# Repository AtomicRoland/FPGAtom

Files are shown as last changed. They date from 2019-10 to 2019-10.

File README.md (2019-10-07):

# FPGAtom

These are the KiCad files of the MK2 boards for the Atom 2k18 a.k.a. FPGAtom. The production files of the MK1 boards are also included but you don't want to use these :-).

For support, create an issue on Github or post your question or remark on the StarDot forums: https://stardot.org.uk/forums/viewtopic.php?f=44&t=15197

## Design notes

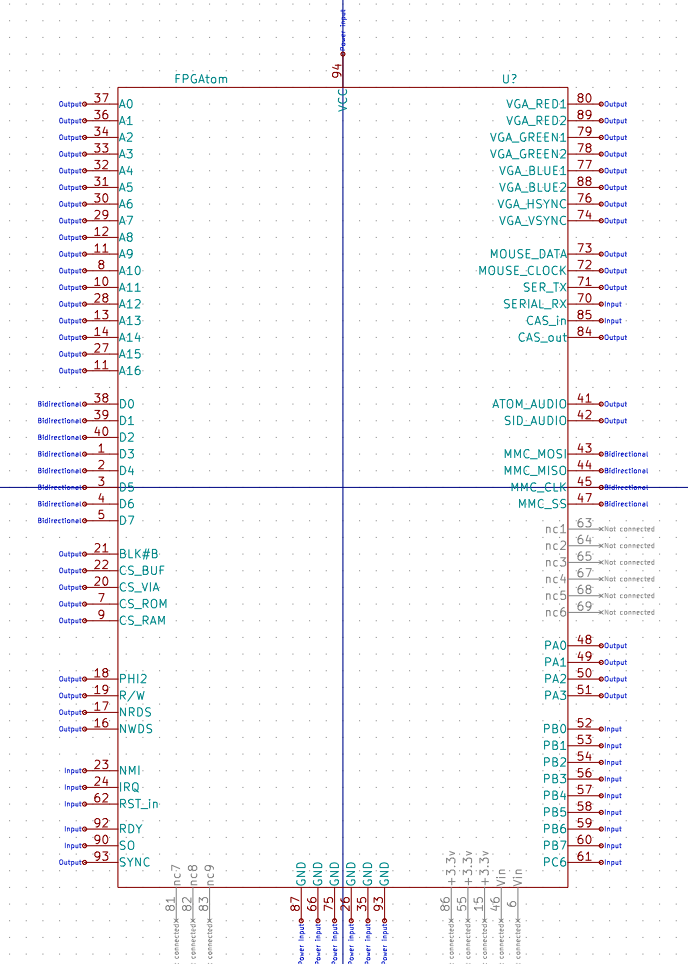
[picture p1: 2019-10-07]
FPGAtom.png

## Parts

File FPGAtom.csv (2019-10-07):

Id | Designator | Package | Quantity | Designation | Supplier and ref
1 | U11 | FPGAmodule | 1 | FPGAtom
2 | R53,R52,R1,R2,R3,R21,R45,R50,R51 | R_Axial_DIN0207_L6.3mm_D2.5mm_P7.62mm_Horizontal | 9 | 4k7
3 | Q4,Q3 | TO-92_Inline_Wide | 2 | BS170
4 | R34,R30,R6,R7,R27,R28,R29,R31,R32,R33 | R_Axial_DIN0207_L6.3mm_D2.5mm_P7.62mm_Horizontal | 10 | R
5 | U6 | DIP-32_W15.24mm_Socket | 1 | AS6C4008-55PCN
6 | J5 Pi Tube | Socket_Strip_Straight_2x20_Pitch2.54mm | 1 | PiTube
7 | J1 (PL7) | DIN41612_B_2x32_Vertical | 1 | Conn_02x32_Row_Letter_First
8 | U5 | DIP-40_W15.24mm_Socket | 1 | 6522
9 | U4,U9,U3 | DIP-20_W7.62mm_Socket | 3 | 74LS244
10 | C11,C3,C5,C6,C7,C12,C15,C16,C17,C18,C2,C4,C9,C13,C14 | C_Rect_L10.0mm_W4.0mm_P7.50mm_MKS4 | 15 | 100nF
11 | U7 | PLCC-32_THT-Socket | 1 | SST39LF040
12 | J8 | DB_15F-VGA | 1 | VGA video
13 | Speaker | Socket_Strip_Straight_2x01_Pitch2.54mm | 1 | Speaker
14 | C1 | CP_Radial_D10.0mm_P5.00mm | 1 | 0,47µF
15 | C10 | CP_Radial_D10.0mm_P5.00mm | 1 | 33µF
16 | D1 | LED_D3.0mm | 1 | RED
17 | D2 | LED_D3.0mm | 1 | GREEN
18 | D3,D4 | D_DO-41_SOD81_P10.16mm_Horizontal | 2 | STPS2L60
19 | J2 (PL6) | DIN41612_B_2x32_Horizontal | 1 | Conn_02x32_Row_Letter_First
20 | J3 | Socket_Strip_Straight_1x03_Pitch2.54mm | 1 | 4M | 1M
21 | J4 | BARREL_JACK | 1 | 5V in
22 | U2 | DIP-20_W7.62mm_Socket | 1 | 74LVC245
23 | Q1,Q2 | TO-92_Inline_Wide | 2 | 2N7000
24 | J12 | Socket_Strip_Straight_1x03_Pitch2.54mm | 1 | Cas Ser
25 | U12 | DIP-8_W7.62mm_Socket | 1 | MCP4822
26 | J19 | Socket_Strip_Straight_1x03_Pitch2.54mm | 1 | Tx 0 Rx
27 | C8 | C_Rect_L10.0mm_W4.0mm_P7.50mm_MKS4 | 1 | 100nF (8x)
28 | C19 | C_Rect_L10.0mm_W4.0mm_P7.50mm_MKS4 | 1 | 100nF (9x)
29 | C20 | C_Rect_L10.0mm_W4.0mm_P7.50mm_MKS4 | 1 | 10nF
30 | C21,C22,C23 | C_Rect_L10.0mm_W4.0mm_P7.50mm_MKS4 | 3 | 0.47µF
31 | C25,C29 | C_Rect_L10.0mm_W4.0mm_P7.50mm_MKS4 | 2 | 47nF
32 | R4,R5,R9 | R_Axial_DIN0207_L6.3mm_D2.5mm_P7.62mm_Horizontal | 3 | 3k3
33 | R8 | R_Axial_DIN0207_L6.3mm_D2.5mm_P7.62mm_Horizontal | 1 | (4x)
34 | R10,R11 | R_Axial_DIN0207_L6.3mm_D2.5mm_P7.62mm_Horizontal | 2 | 220Ω
35 | R12,R25 | R_Axial_DIN0207_L6.3mm_D2.5mm_P7.62mm_Horizontal | 2 | 82Ω
36 | R13,R15,R16,R18,R38,R39,R41,R44,R46,R36,R37,R42,R43 | R_Axial_DIN0207_L6.3mm_D2.5mm_P7.62mm_Horizontal | 13 | 10kΩ
37 | R14,R19,R22 | R_Axial_DIN0207_L6.3mm_D2.5mm_P7.62mm_Horizontal | 3 | 680Ω
38 | R17,R20,R24 | R_Axial_DIN0207_L6.3mm_D2.5mm_P7.62mm_Horizontal | 3 | 180Ω
39 | R23,R35 | R_Axial_DIN0207_L6.3mm_D2.5mm_P7.62mm_Horizontal | 2 | 1kΩ
40 | R26 | R_Axial_DIN0207_L6.3mm_D2.5mm_P7.62mm_Horizontal | 1 | 9x 3k3
41 | R40 | R_Axial_DIN0207_L6.3mm_D2.5mm_P7.62mm_Horizontal | 1 | 470kΩ
42 | R47,R49 | R_Axial_DIN0207_L6.3mm_D2.5mm_P7.62mm_Horizontal | 2 | 47kΩ
43 | R48 | R_Axial_DIN0207_L6.3mm_D2.5mm_P7.62mm_Horizontal | 1 | 10Ω
44 | RV1 | Potentiometer_Trimmer_Suntan_TSR-3386P_Horizontal | 1 | 10kΩ
45 | RV2,RV3 | Potentiometer_Trimmer_Suntan_TSR-3386P_Horizontal | 2 | 10KΩ
46 | C24 | CP_Radial_D10.0mm_P5.00mm | 1 | 10µF
47 | C26 | CP_Radial_D10.0mm_P5.00mm | 1 | 0.47µF
48 | C27 | CP_Radial_D10.0mm_P5.00mm | 1 | 22µF
49 | C28 | CP_Radial_D10.0mm_P5.00mm | 1 | 220µF
50 | J6 | Socket_Strip_Straight_1x02_Pitch2.54mm | 1 | PiPower
51 | J7 | Socket_Strip_Straight_1x02_Pitch2.54mm | 1 | PS/2 KB enable
52 | J9 | SD-MMC | 1 | SD_Card
53 | J10 | Socket_Strip_Straight_1x02_Pitch2.54mm | 1 | Audio1
54 | J11 | Socket_Strip_Straight_1x02_Pitch2.54mm | 1 | Audio2
55 | J13 | Socket_Strip_Straight_1x03_Pitch2.54mm | 1 | Ser Cas
56 | J14 | Pin_Header_Straight_2x13_Pitch2.54mm | 1 | Keyboard connector
57 | J15 | Jack_35_5p | 1 | Audio
58 | J16 | PS2 | 1 | PS/2 Mouse
59 | J17 | PS2 | 1 | PS/2 keyboard
60 | J18 | DSUB-15_Female_Horizontal_P2.77x2.84mm_EdgePinOffset4.94mm_Housed_MountingHolesOffset7.48mm | 1 | DAC/Serial/Cass/Joystick
61 | U1 | TSOP-II-44_10.16x18.41mm_P0.8mm | 1 | CY7C1049GN30-10ZSXI
62 | U8 | TO-220-3_Horizontal | 1 | LM3940
63 | U10,U15 | DIP-20_W7.62mm_Socket | 2 | 74LVC244
64 | U13 | DIP-8_W7.62mm_Socket | 1 | LM358
65 | U14 | DIP-16_W7.62mm_Socket | 1 | 7445
66 | U16 | DIP-8_W7.62mm_Socket | 1 | LM386
67 | H1,H2 | MountingHole_4mm | 2 | MountingHole
68 | H3,H4 | MountingHole_6mm | 2 | MountingHole

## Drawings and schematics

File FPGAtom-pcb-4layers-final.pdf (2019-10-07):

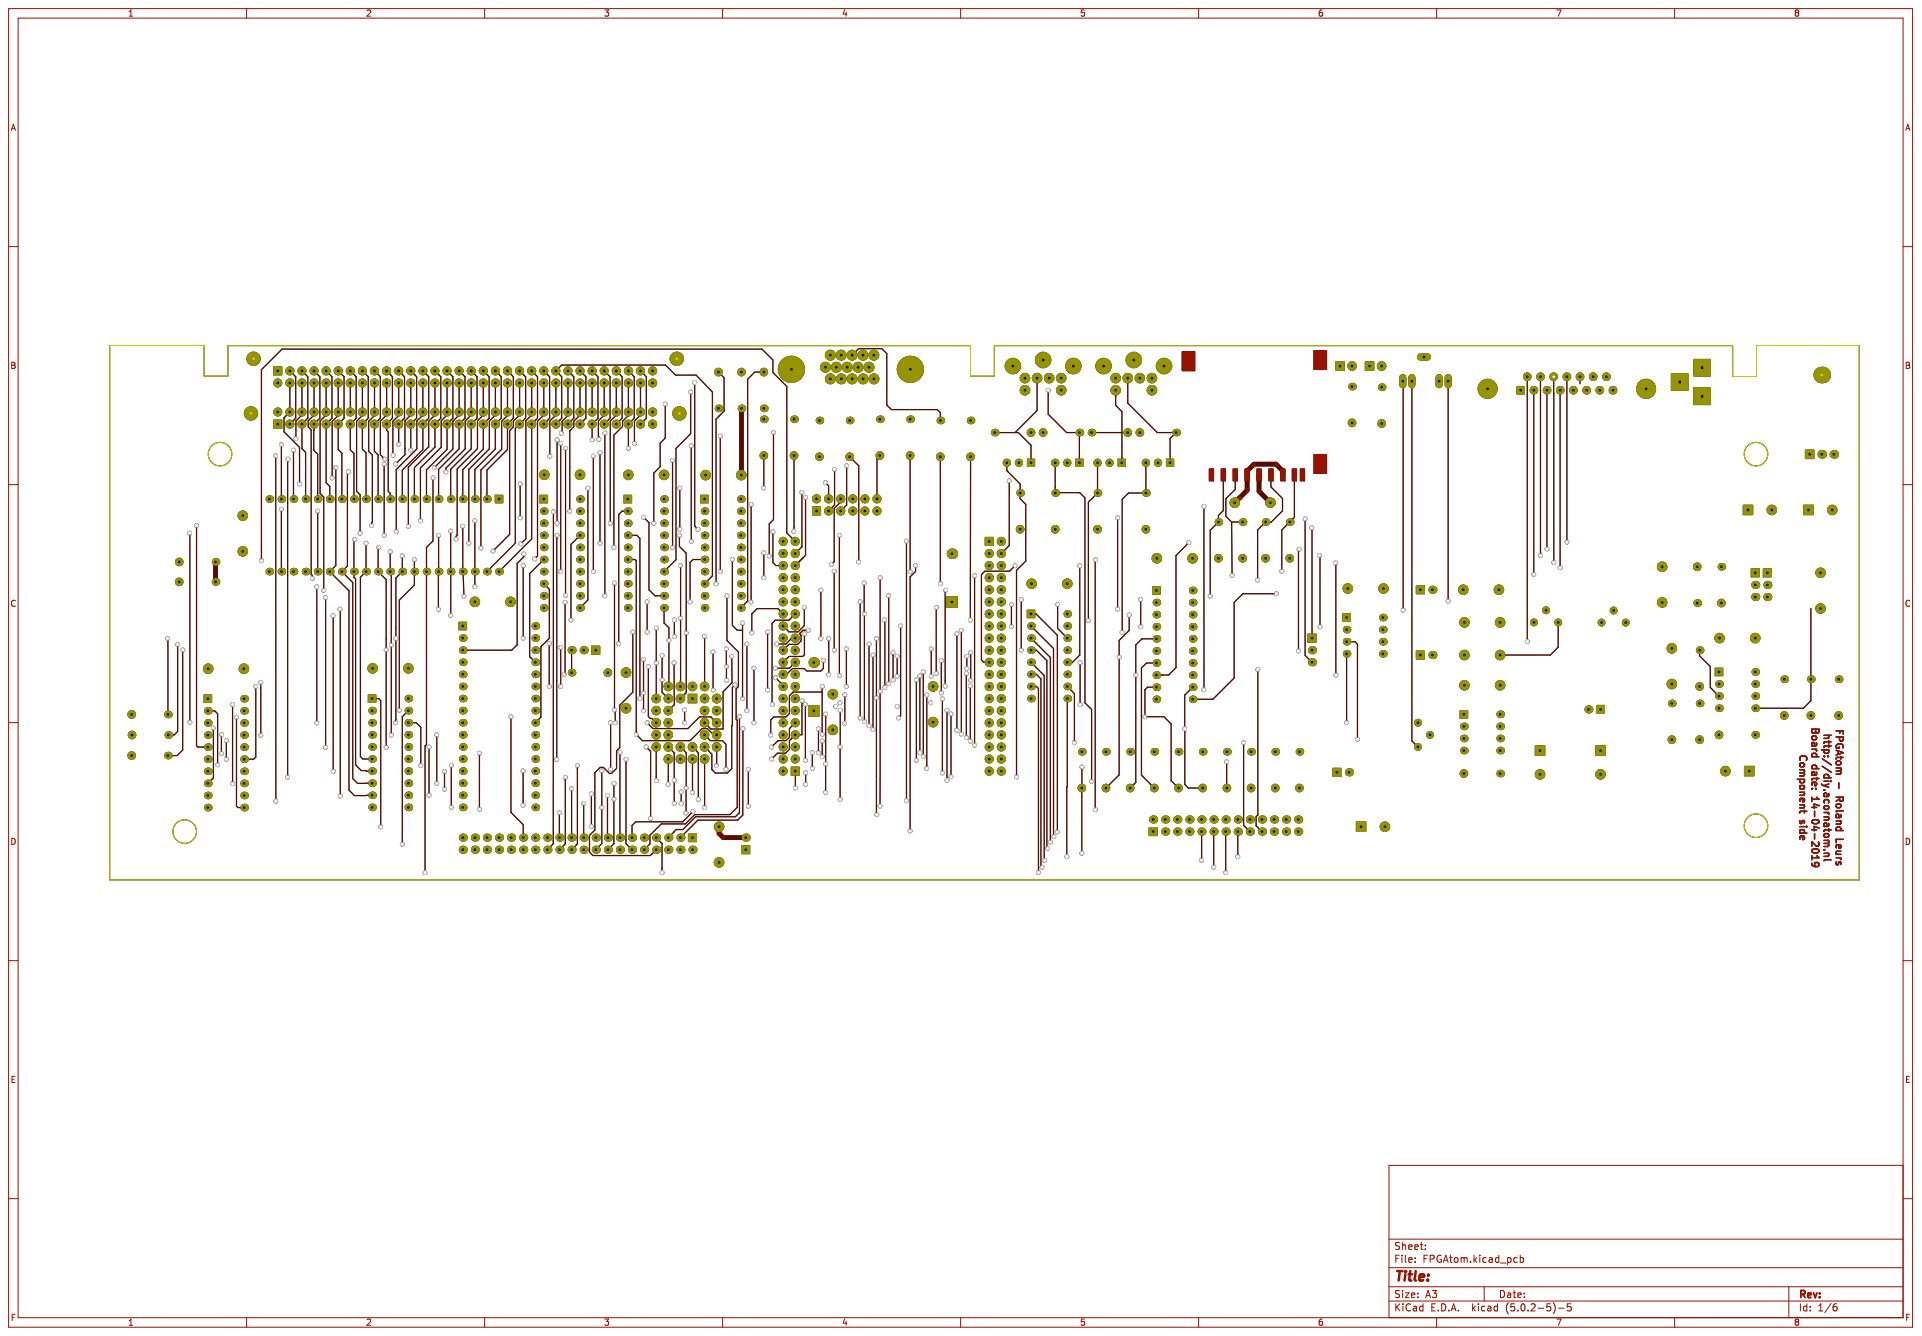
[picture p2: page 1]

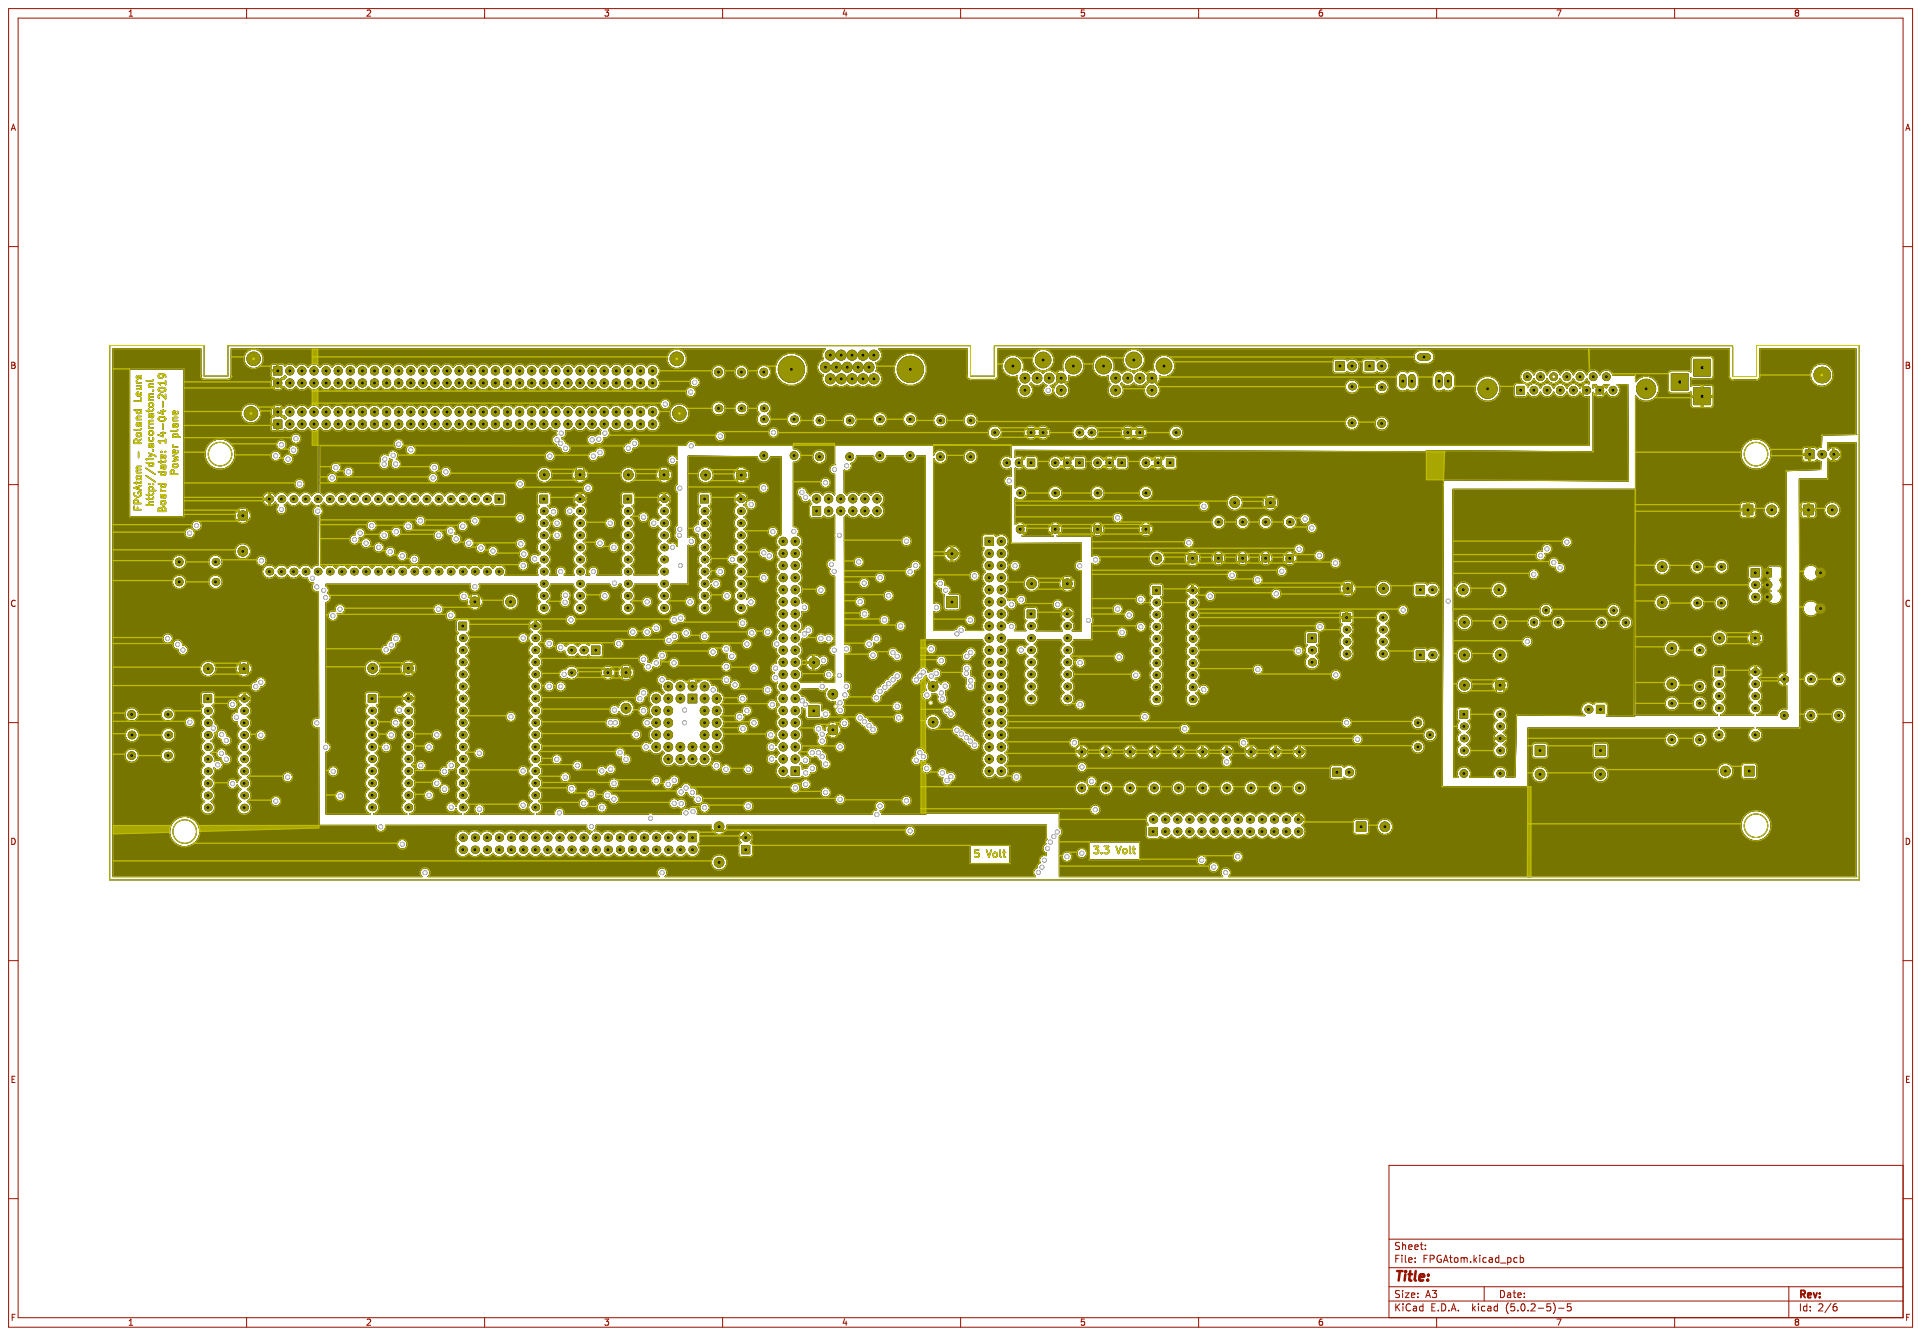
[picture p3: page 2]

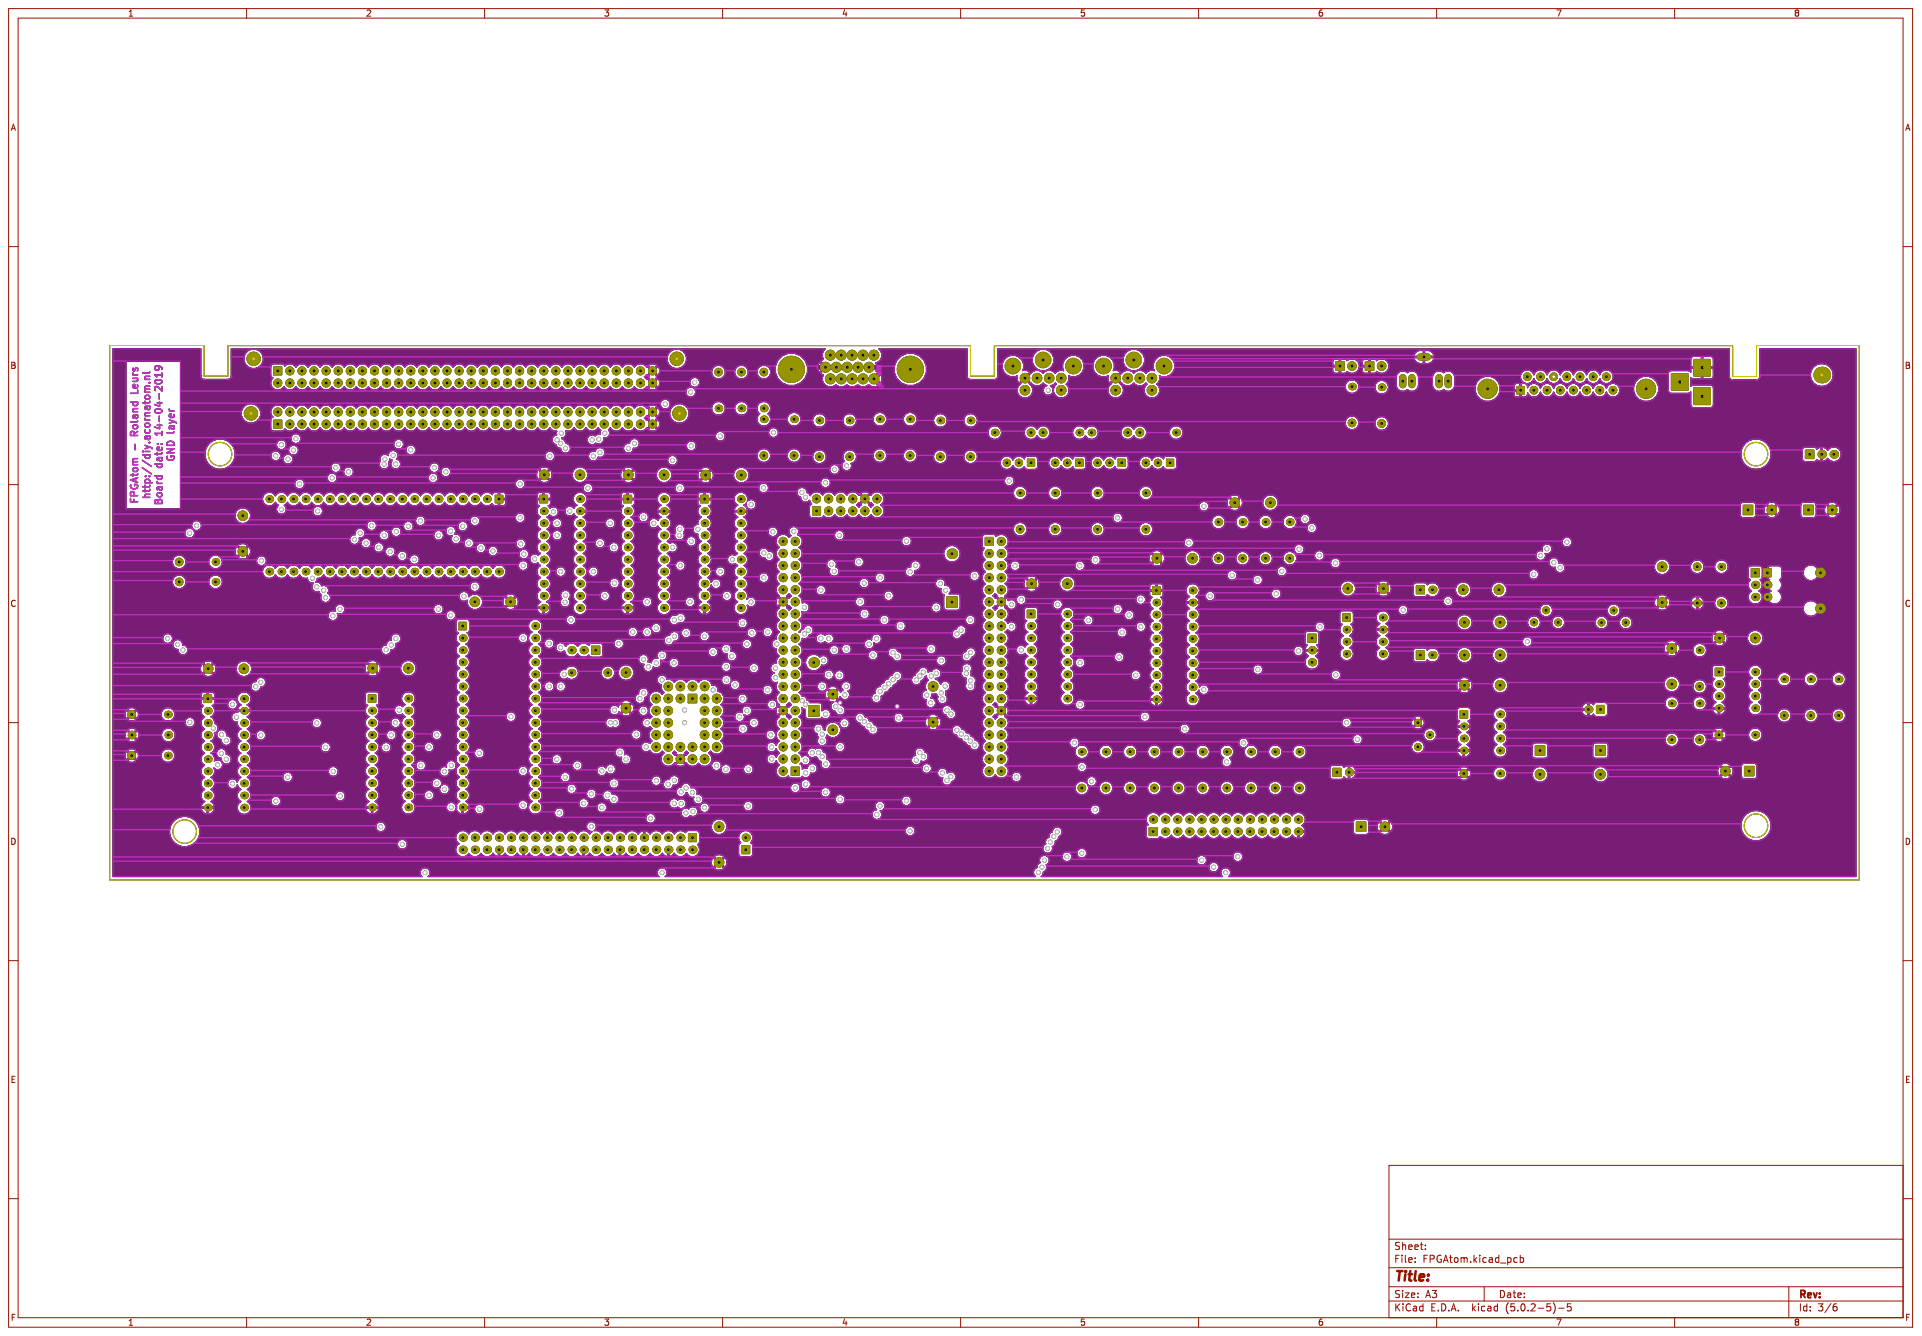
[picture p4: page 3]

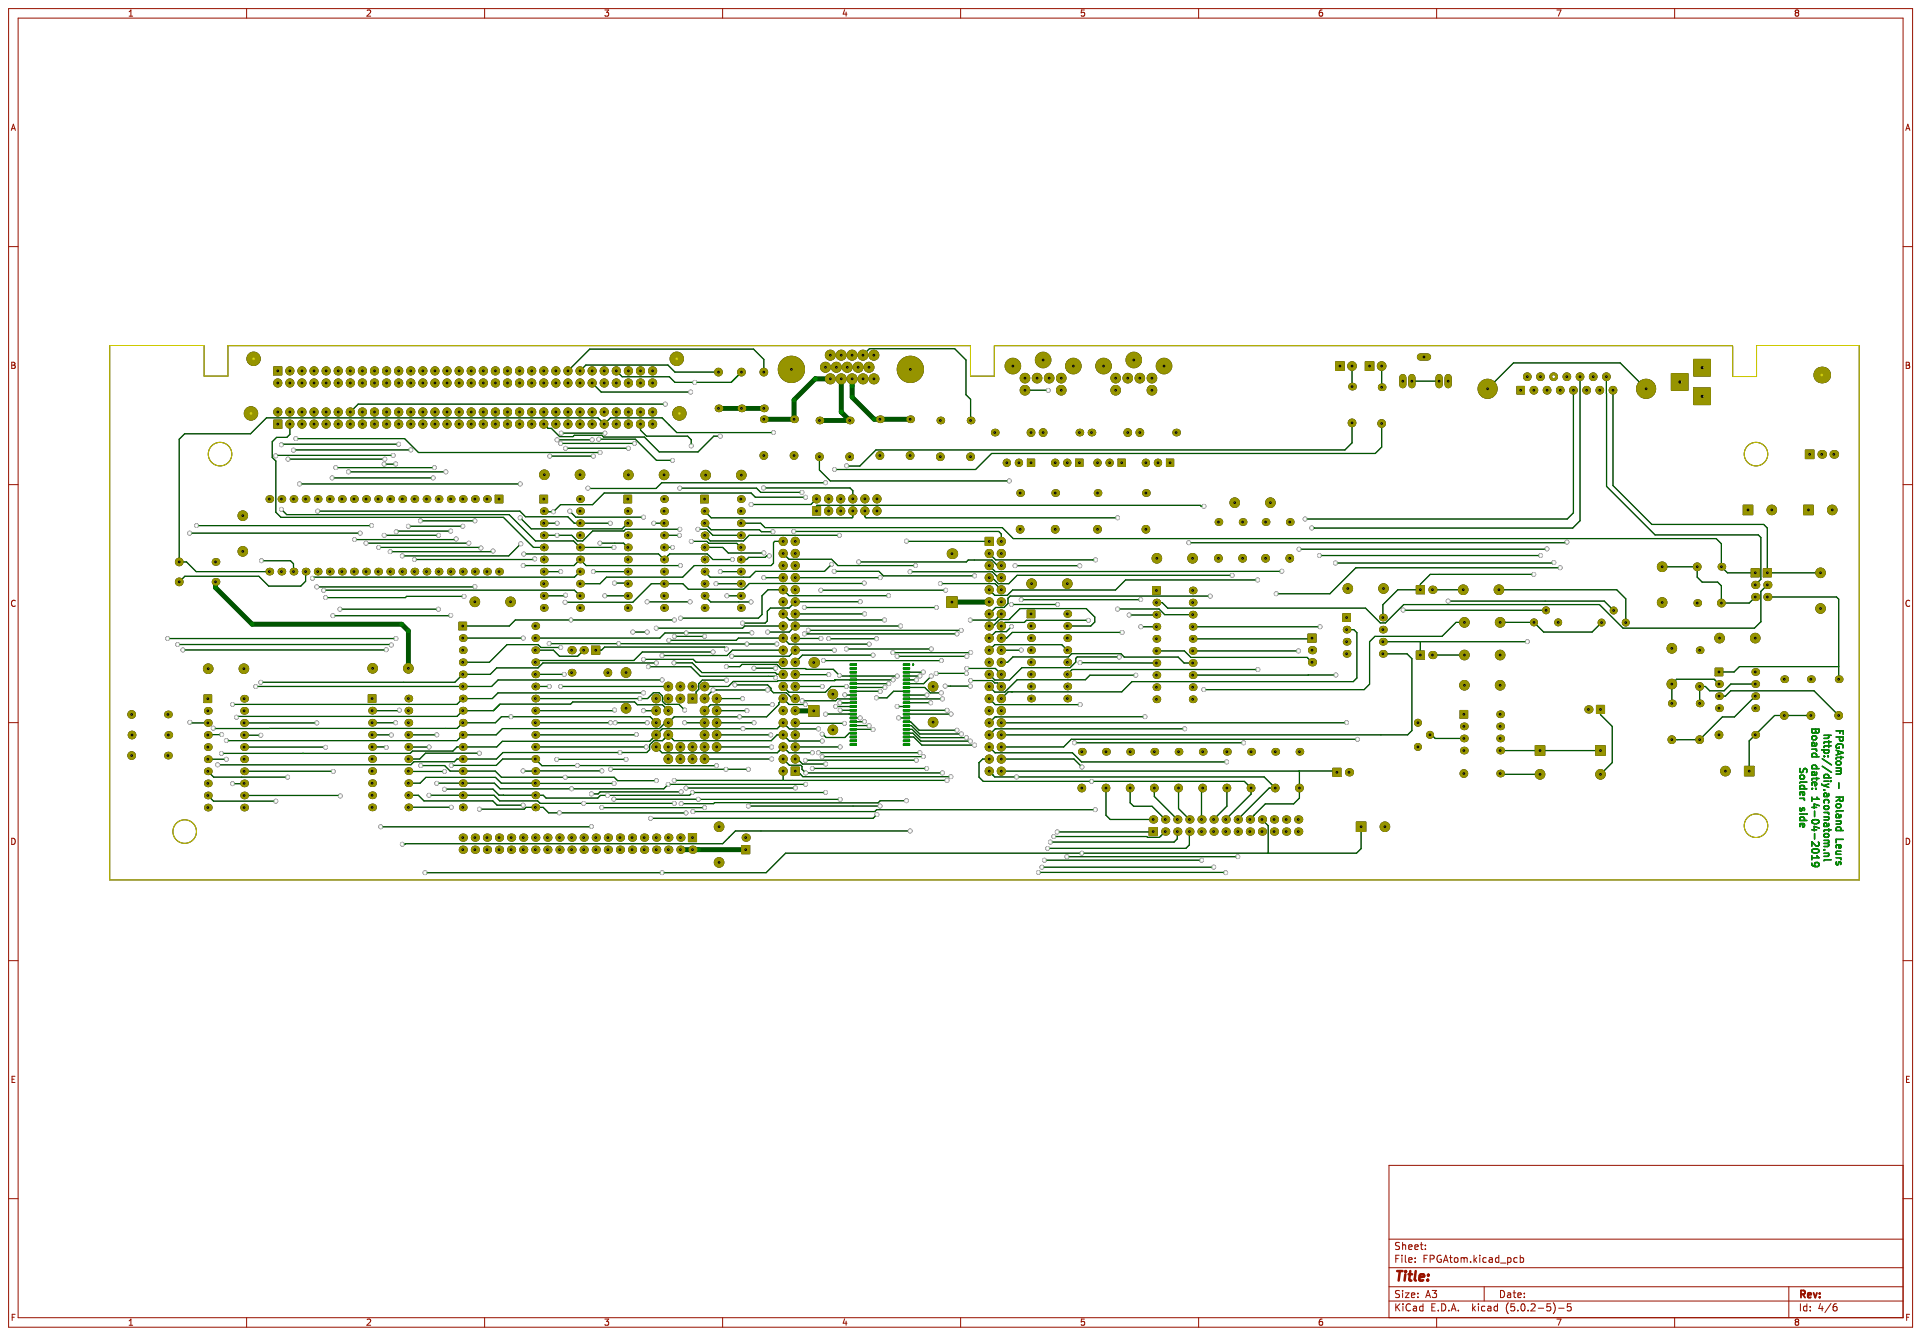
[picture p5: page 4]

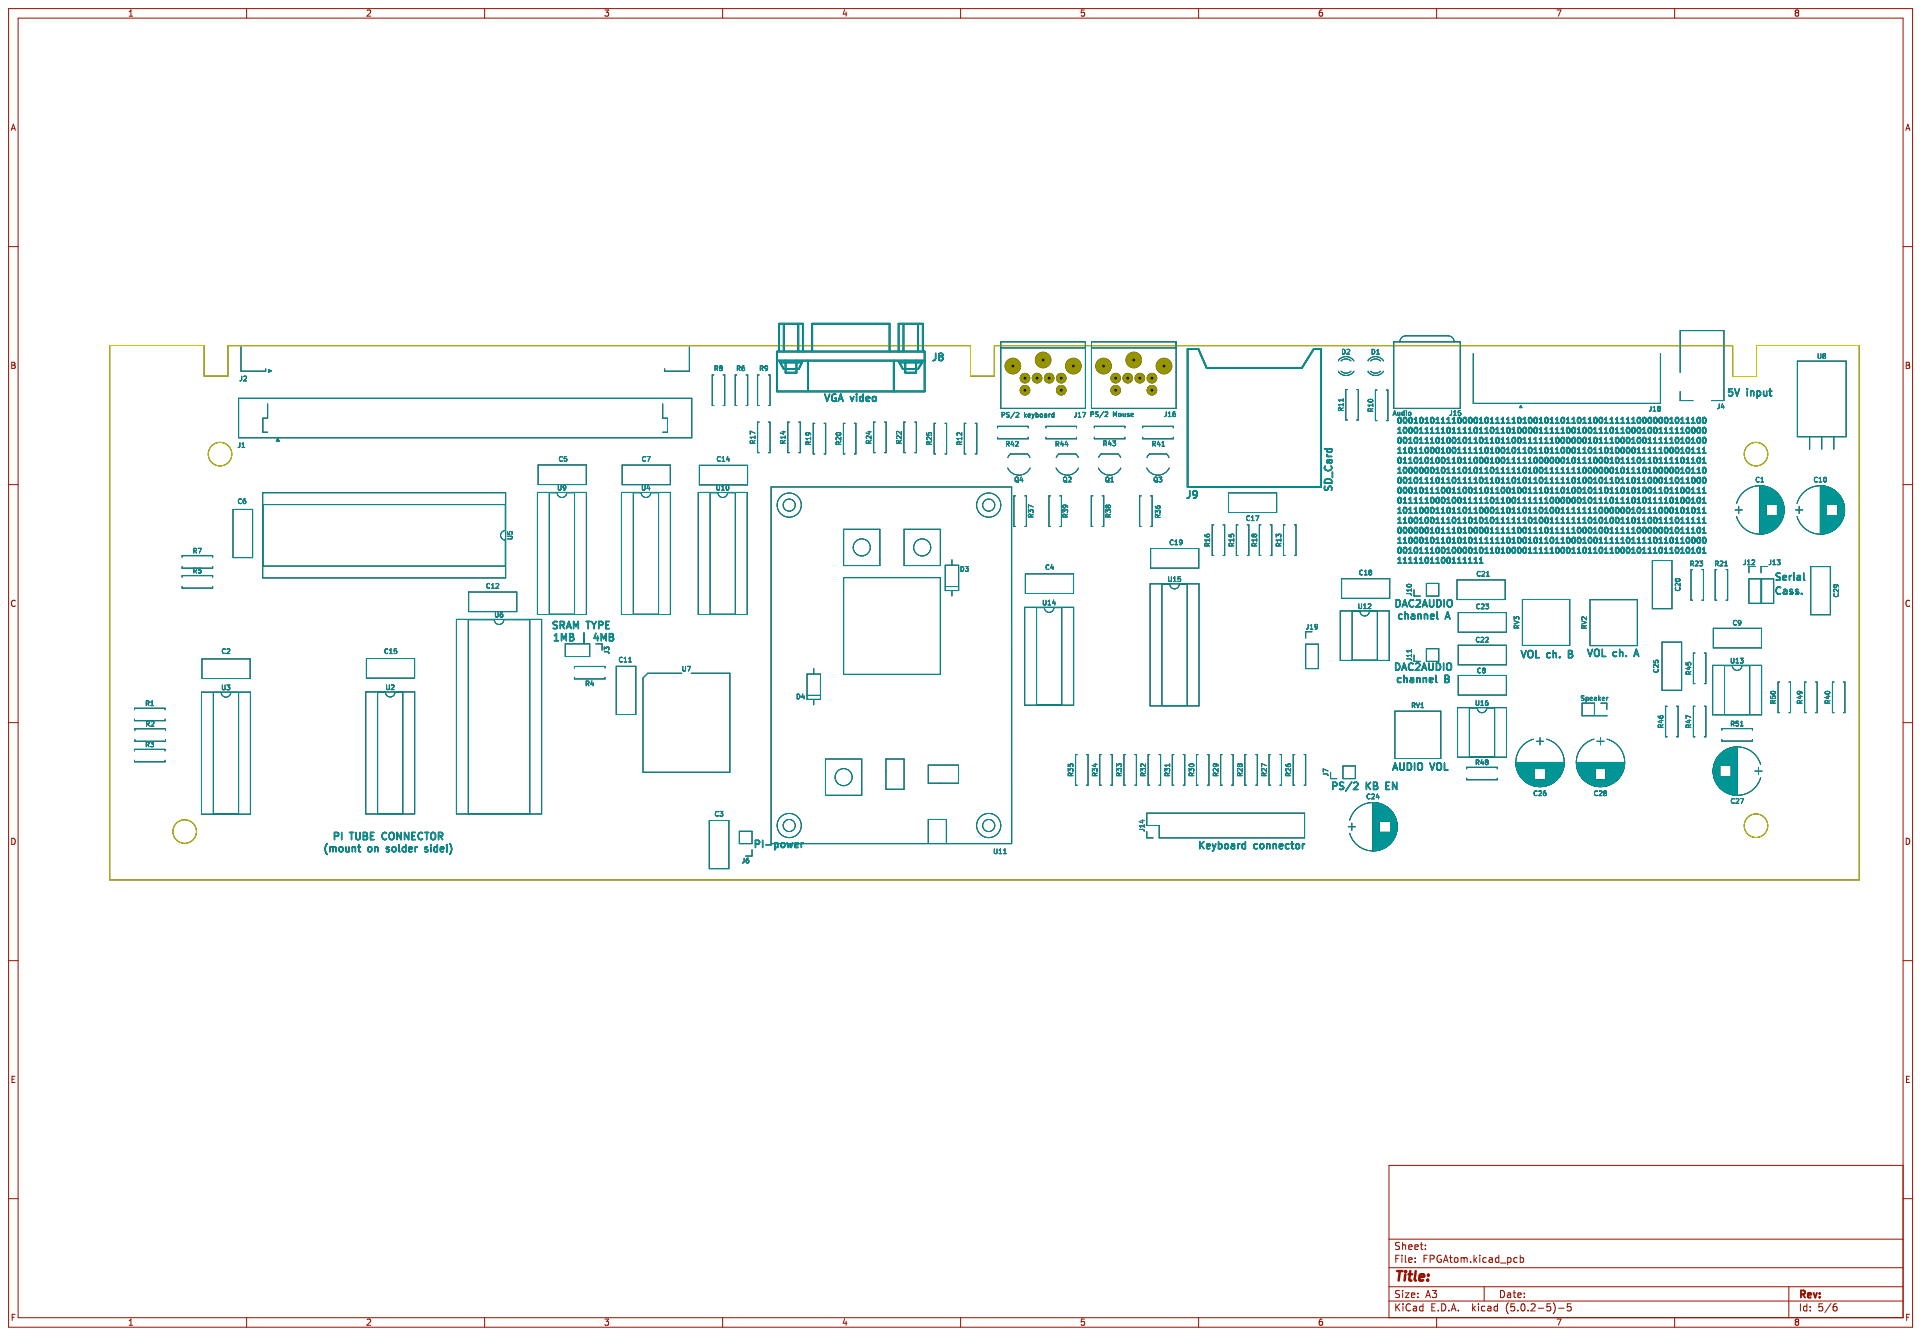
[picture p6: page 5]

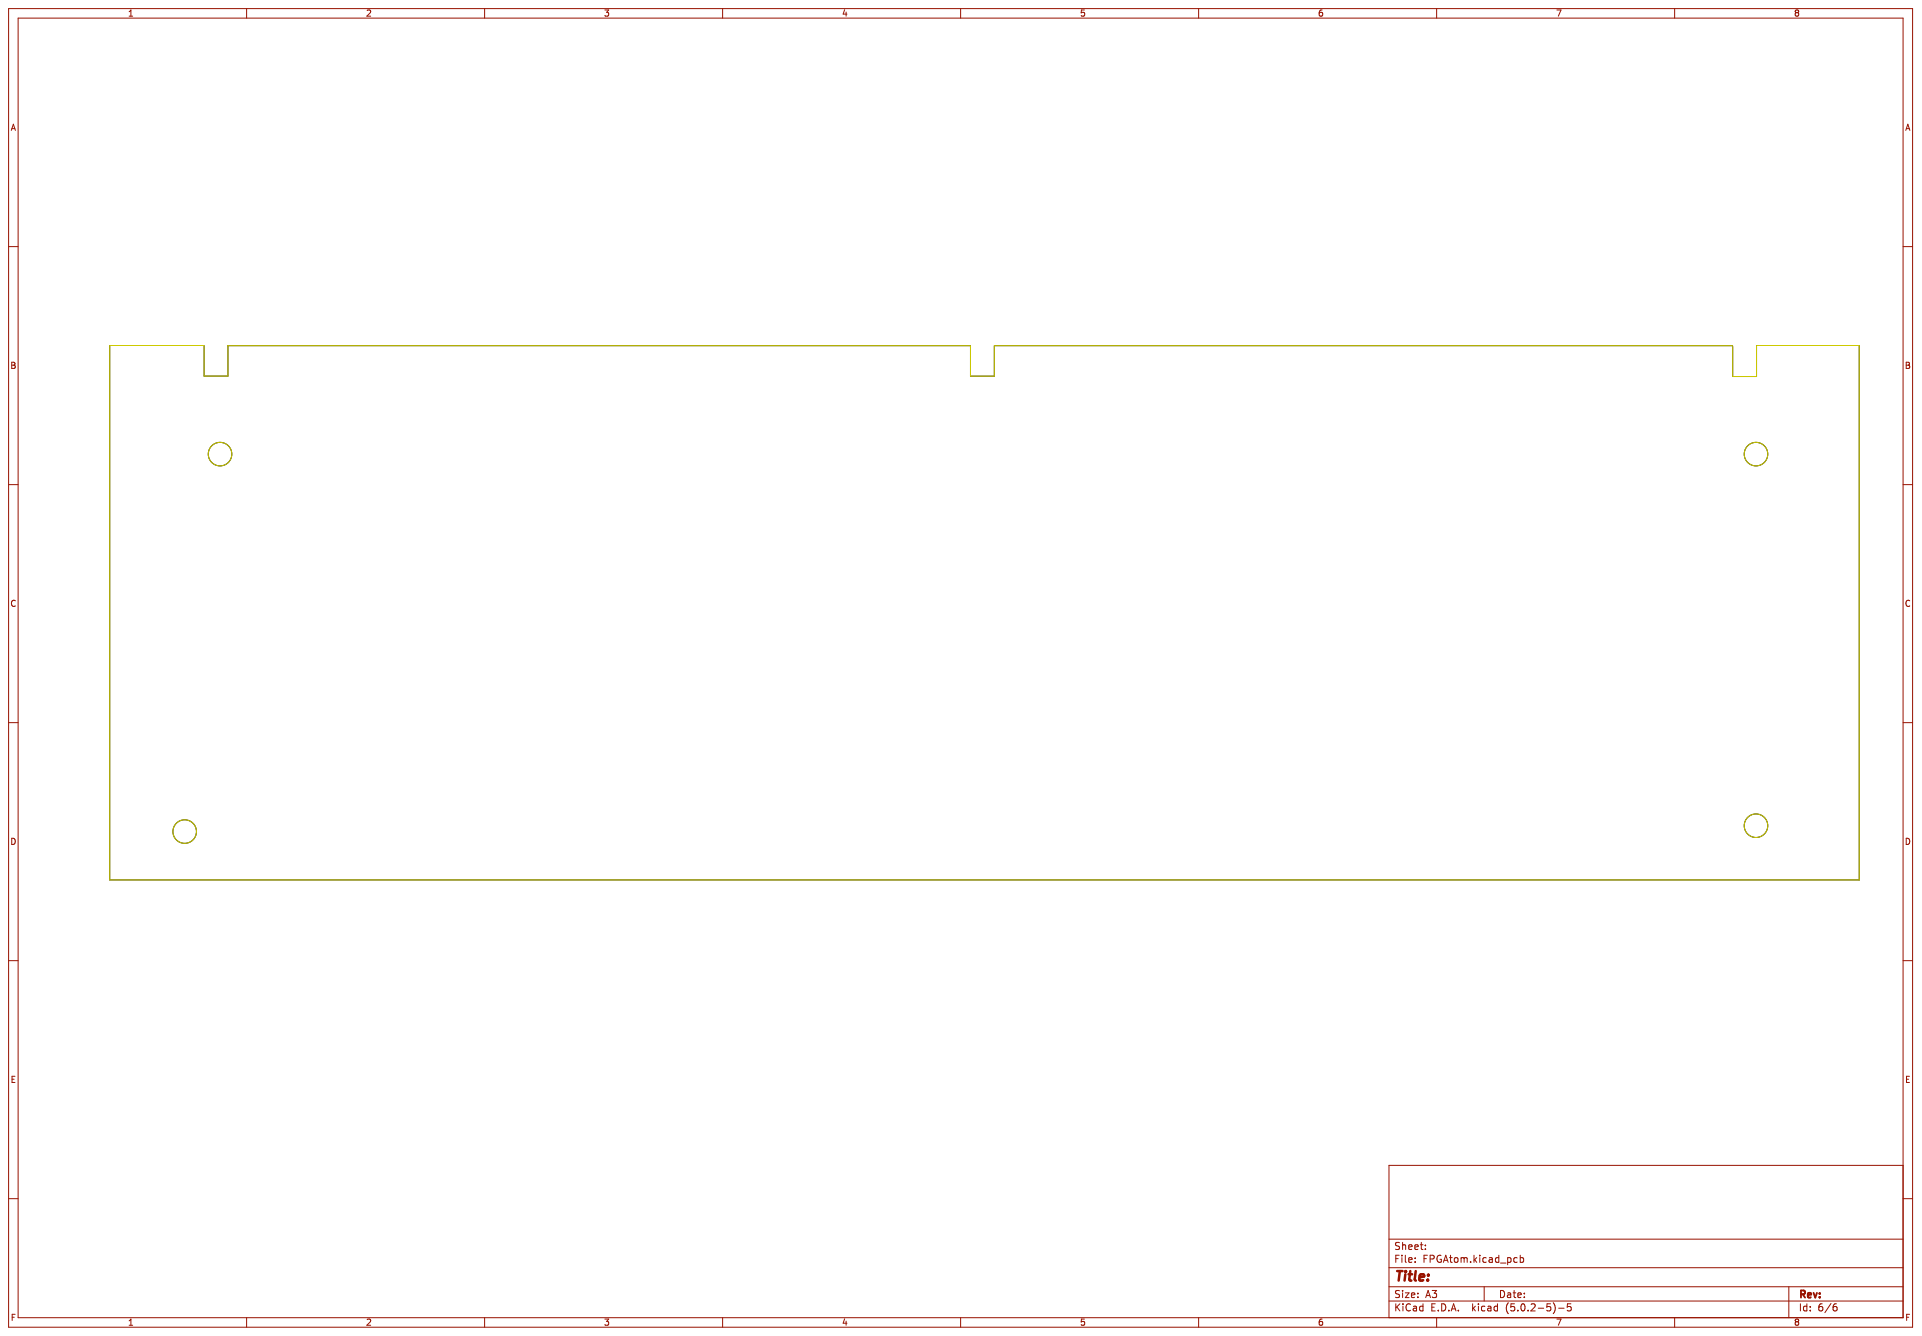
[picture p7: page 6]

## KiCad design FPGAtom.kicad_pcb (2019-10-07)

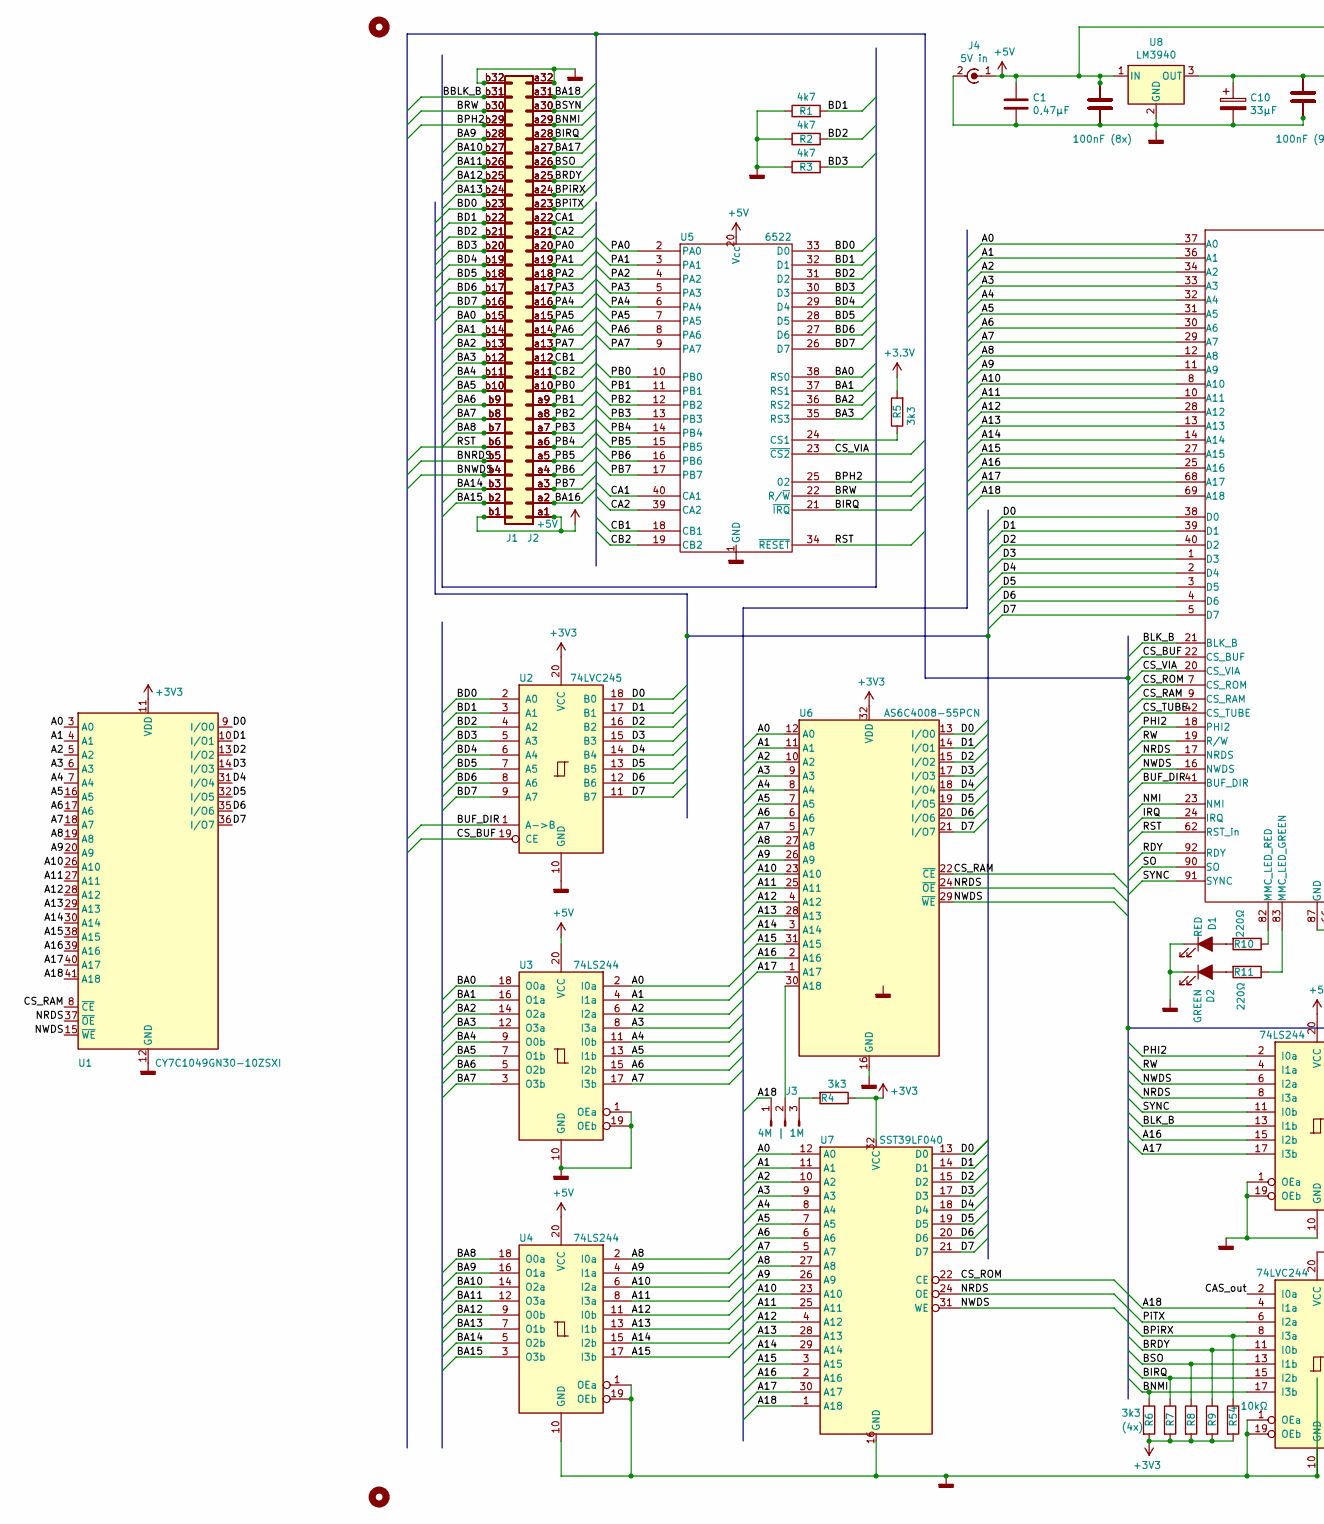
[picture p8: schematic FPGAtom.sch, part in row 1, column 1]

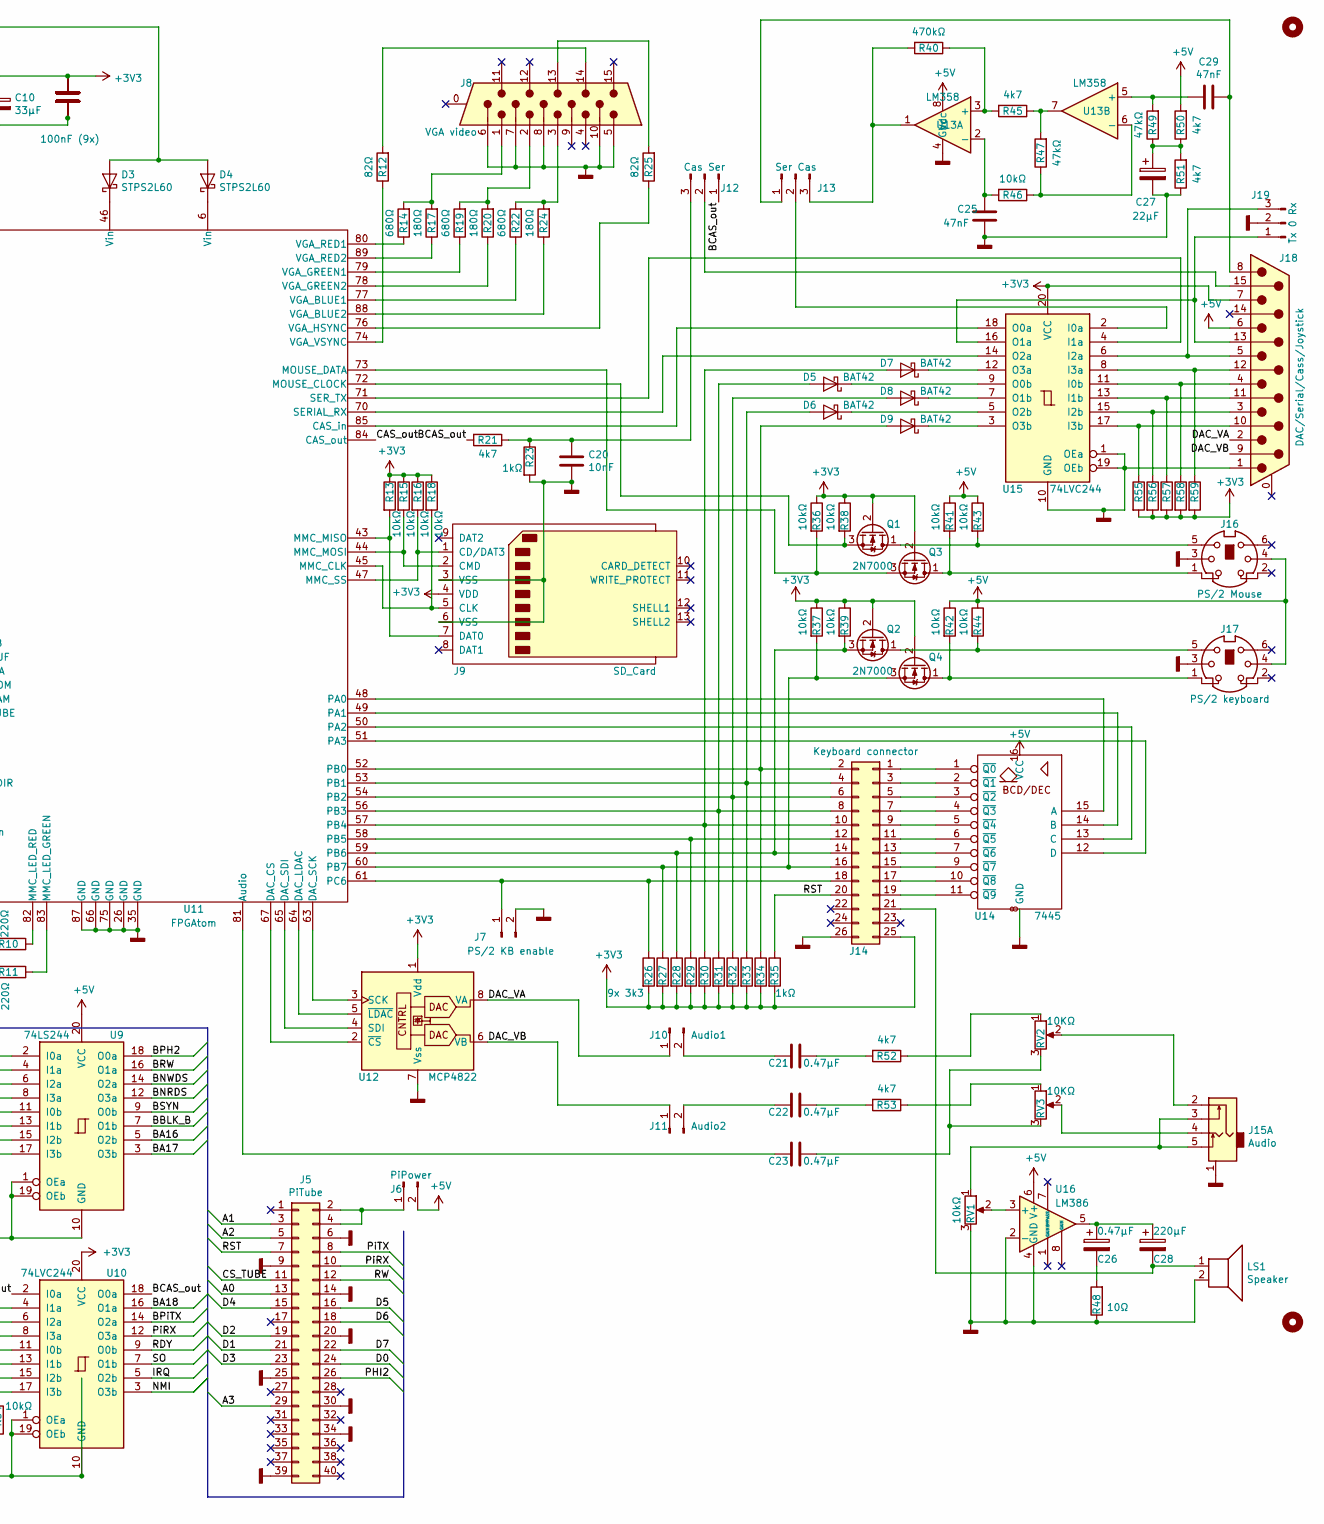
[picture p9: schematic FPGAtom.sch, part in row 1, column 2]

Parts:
C1: 0,47µF; CP_Radial_D10.0mm_P5.00mm
C2, C3, C4, C5, C6, C7, C9, C11, C12, C13, C14, C15, C16, C17, C18: 100nF; C_Rect_L10.0mm_W4.0mm_P7.50mm_MKS4
C8: 100nF (8x); C_Rect_L10.0mm_W4.0mm_P7.50mm_MKS4
C10: 33µF; CP_Radial_D10.0mm_P5.00mm
C19: 100nF (9x); C_Rect_L10.0mm_W4.0mm_P7.50mm_MKS4
C20: 10nF; C_Rect_L10.0mm_W4.0mm_P7.50mm_MKS4
C21, C22, C23: 0.47µF; C_Rect_L10.0mm_W4.0mm_P7.50mm_MKS4
C25, C29: 47nF; C_Rect_L10.0mm_W4.0mm_P7.50mm_MKS4
C26: 0.47µF; CP_Radial_D10.0mm_P5.00mm
C27: 22µF; CP_Radial_D10.0mm_P5.00mm
C28: 220µF; CP_Radial_D10.0mm_P5.00mm
D1: RED; LED_D3.0mm
D2: GREEN; LED_D3.0mm
D3, D4: STPS2L60; D_DO-41_SOD81_P10.16mm_Horizontal
D5, D6, D7, D8, D9: BAT42; D_A-405_P7.62mm_Horizontal
H1, H2: MountingHole; MountingHole_4mm
H3, H4: MountingHole; MountingHole_6mm
J1: Conn_02x32_Row_Letter_First; DIN41612_B_2x32_Vertical
J2: Conn_02x32_Row_Letter_First; DIN41612_B_2x32_Horizontal
J3: 4M | 1M; Socket_Strip_Straight_1x03_Pitch2.54mm
J4: 5V in; BARREL_JACK
J5: PiTube; Socket_Strip_Straight_2x20_Pitch2.54mm
J6: PiPower; Socket_Strip_Straight_1x02_Pitch2.54mm
J7: PS/2 KB enable; Socket_Strip_Straight_1x02_Pitch2.54mm
J8: VGA video; DSUB-15-HD_Male_Horizontal_P2.29x1.98mm_EdgePinOffset8.35mm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
J9: SD_Card; SD-MMC
J10: Audio1; Socket_Strip_Straight_1x02_Pitch2.54mm
J11: Audio2; Socket_Strip_Straight_1x02_Pitch2.54mm
J12: Cas Ser; Socket_Strip_Straight_1x03_Pitch2.54mm
J13: Ser Cas; Socket_Strip_Straight_1x03_Pitch2.54mm
J14: Keyboard connector; Pin_Header_Straight_2x13_Pitch2.54mm
J15: Audio; Jack_35_5p
J16: PS/2 Mouse; PS2
J17: PS/2 keyboard; PS2
J18: DAC/Serial/Cass/Joystick; DSUB-15_Female_Horizontal_P2.77x2.84mm_EdgePinOffset4.94mm_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
J19: Tx 0 Rx; Socket_Strip_Straight_1x03_Pitch2.54mm
LS1: Speaker; Socket_Strip_Straight_1x02_Pitch2.54mm
Q1, Q2: 2N7000; TO-92_Inline_Wide
Q3, Q4: BS170; TO-92_Inline_Wide
R1, R2, R3, R21, R45, R50, R51, R52, R53: 4k7; R_Axial_DIN0207_L6.3mm_D2.5mm_P7.62mm_Horizontal
R4, R5, R9, R55, R56, R57, R58, R59: 3k3; R_Axial_DIN0207_L6.3mm_D2.5mm_P7.62mm_Horizontal
R6, R7, R27, R28, R29, R30, R31, R32, R33, R34: R; R_Axial_DIN0207_L6.3mm_D2.5mm_P7.62mm_Horizontal
R8: (4x); R_Axial_DIN0207_L6.3mm_D2.5mm_P7.62mm_Horizontal
R10, R11: 220Ω; R_Axial_DIN0207_L6.3mm_D2.5mm_P7.62mm_Horizontal
R12, R25: 82Ω; R_Axial_DIN0207_L6.3mm_D2.5mm_P7.62mm_Horizontal
R13, R15, R16, R18, R36, R37, R38, R39, R41, R42, R43, R44, R46, R54: 10kΩ; R_Axial_DIN0207_L6.3mm_D2.5mm_P7.62mm_Horizontal
R14, R19, R22: 680Ω; R_Axial_DIN0207_L6.3mm_D2.5mm_P7.62mm_Horizontal
R17, R20, R24: 180Ω; R_Axial_DIN0207_L6.3mm_D2.5mm_P7.62mm_Horizontal
R23, R35: 1kΩ; R_Axial_DIN0207_L6.3mm_D2.5mm_P7.62mm_Horizontal
R26: 9x 3k3; R_Axial_DIN0207_L6.3mm_D2.5mm_P7.62mm_Horizontal
R40: 470kΩ; R_Axial_DIN0207_L6.3mm_D2.5mm_P7.62mm_Horizontal
R47, R49: 47kΩ; R_Axial_DIN0207_L6.3mm_D2.5mm_P7.62mm_Horizontal
R48: 10Ω; R_Axial_DIN0207_L6.3mm_D2.5mm_P7.62mm_Horizontal
RV1: 10kΩ; Potentiometer_Trimmer_Suntan_TSR-3386P_Horizontal
RV2, RV3: 10KΩ; Potentiometer_Trimmer_Suntan_TSR-3386P_Horizontal
U1: CY7C1049GN30-10ZSXI; TSOP-II-44_10.16x18.41mm_P0.8mm
U2: 74LVC245; DIP-20_W7.62mm_Socket
U3, U4, U9: 74LS244; DIP-20_W7.62mm_Socket
U5: 6522; DIP-40_W15.24mm_Socket
U6: AS6C4008-55PCN; DIP-32_W15.24mm_Socket
U7: SST39LF040; PLCC-32_THT-Socket
U8: LM3940; TO-220-3_Horizontal
U10, U15: 74LVC244; DIP-20_W7.62mm_Socket
U11: FPGAtom; FPGAmodule
U12: MCP4822; DIP-8_W7.62mm_Socket
U13: LM358; DIP-8_W7.62mm_Socket
U14: 7445; DIP-16_W7.62mm_Socket
U16: LM386; DIP-8_W7.62mm_Socket

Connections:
+5V: C1.1, C2.1, C3.1, C4.1, C5.1, C6.1, C7.1, C8.1, C9.1, D3.2 (A), D4.2 (A), J1.a1, J1.b1, J2.a1, J2.b1, J4.1 (In), J6.2, J16.4, J17.4, J18.6, R41.1, R42.1, R43.1, R44.1, R50.2, U3.20 (VCC), U4.20 (VCC), U5.20 (Vcc), U8.1 (IN), U9.20 (VCC), U13.8 (Vcc), U14.16 (VCC), U16.6 (V+); also elsewhere on the board
/A0: J5.13, U1.3 (A0), U3.2 (I0a), U6.12 (A0), U7.12 (A0), U11.37 (A0); also elsewhere on the board
/A1: J5.3, U1.4 (A1), U3.4 (I1a), U6.11 (A1), U7.11 (A1), U11.36 (A1); also elsewhere on the board
/A2: J5.5, U1.5 (A2), U3.6 (I2a), U6.10 (A2), U7.10 (A2), U11.34 (A2); also elsewhere on the board
/A3: J5.29, U1.6 (A3), U3.8 (I3a), U6.9 (A3), U7.9 (A3), U11.33 (A3); also elsewhere on the board
/A4: U1.7 (A4), U3.11 (I0b), U6.8 (A4), U7.8 (A4), U11.32 (A4)
/A5: U1.16 (A5), U3.13 (I1b), U6.7 (A5), U7.7 (A5), U11.31 (A5)
/A6: U1.17 (A6), U3.15 (I2b), U6.6 (A6), U7.6 (A6), U11.30 (A6)
/A7: U1.18 (A7), U3.17 (I3b), U6.5 (A7), U7.5 (A7), U11.29 (A7)
/A8: U1.19 (A8), U4.2 (I0a), U6.27 (A8), U7.27 (A8), U11.12 (A8)
/A9: U1.20 (A9), U4.4 (I1a), U6.26 (A9), U7.26 (A9), U11.11 (A9)
/A10: U1.26 (A10), U4.6 (I2a), U6.23 (A10), U7.23 (A10), U11.8 (A10)
/A11: U1.27 (A11), U4.8 (I3a), U6.25 (A11), U7.25 (A11), U11.10 (A11)
/A12: U1.28 (A12), U4.11 (I0b), U6.4 (A12), U7.4 (A12), U11.28 (A12)
/A13: U1.29 (A13), U4.13 (I1b), U6.28 (A13), U7.28 (A13), U11.13 (A13)
/A14: U1.30 (A14), U4.15 (I2b), U6.3 (A14), U7.29 (A14), U11.14 (A14)
/A15: U1.38 (A15), U4.17 (I3b), U6.31 (A15), U7.3 (A15), U11.27 (A15)
/A16: U1.39 (A16), U6.2 (A16), U7.2 (A16), U9.15 (I2b), U11.25 (A16)
/A17: U1.40 (A17), U6.1 (A17), U7.30 (A17), U9.17 (I3b), U11.68 (A17)
/A18: J3.1, U1.41 (A18), U7.1 (A18), U10.4 (I1a), U11.69 (A18)
/BA0: J1.b15, J2.b15, U3.18 (O0a), U5.38 (RS0); also elsewhere on the board
/BA1: J1.b14, J2.b14, U3.16 (O1a), U5.37 (RS1); also elsewhere on the board
/BA2: J1.b13, J2.b13, U3.14 (O2a), U5.36 (RS2); also elsewhere on the board
/BA3: J1.b12, J2.b12, U3.12 (O3a), U5.35 (RS3); also elsewhere on the board
/BA4: J1.b11, J2.b11, U3.9 (O0b); also elsewhere on the board
/BA5: J1.b10, J2.b10, U3.7 (O1b); also elsewhere on the board
/BA6: J1.b9, J2.b9, U3.5 (O2b); also elsewhere on the board
/BA7: J1.b8, J2.b8, U3.3 (O3b); also elsewhere on the board
/BA8: J1.b7, J2.b7, U4.18 (O0a); also elsewhere on the board
/BA9: J1.b28, J2.b28, U4.16 (O1a); also elsewhere on the board
/BA10: J1.b27, J2.b27, U4.14 (O2a); also elsewhere on the board
/BA11: J1.b26, J2.b26, U4.12 (O3a); also elsewhere on the board
/BA12: J1.b25, J2.b25, U4.9 (O0b); also elsewhere on the board
/BA13: J1.b24, J2.b24, U4.7 (O1b); also elsewhere on the board
/BA14: J1.b3, J2.b3, U4.5 (O2b); also elsewhere on the board
/BA15: J1.b2, J2.b2, U4.3 (O3b); also elsewhere on the board
/BA16: J1.a2, J2.a2, U9.5 (O2b); also elsewhere on the board
/BA17: J1.a27, J2.a27, U9.3 (O3b); also elsewhere on the board
/BA18: J1.a31, J2.a31, U10.16 (O1a); also elsewhere on the board
/BBLK_B: J1.b31, J2.b31, U9.7 (O1b); also elsewhere on the board
/BCAS_out: J12.1, R21.2, U10.18 (O0a)
/BD0: J1.b23, J2.b23, U2.2 (A0), U5.33 (D0); also elsewhere on the board
/BD1: J1.b22, J2.b22, R1.2, U2.3 (A1), U5.32 (D1); also elsewhere on the board
/BD2: J1.b21, J2.b21, R2.2, U2.4 (A2), U5.31 (D2); also elsewhere on the board
/BD3: J1.b20, J2.b20, R3.2, U2.5 (A3), U5.30 (D3); also elsewhere on the board
/BD4: J1.b19, J2.b19, U2.6 (A4), U5.29 (D4); also elsewhere on the board
/BD5: J1.b18, J2.b18, U2.7 (A5), U5.28 (D5); also elsewhere on the board
/BD6: J1.b17, J2.b17, U2.8 (A6), U5.27 (D6); also elsewhere on the board
/BD7: J1.b16, J2.b16, U2.9 (A7), U5.26 (D7); also elsewhere on the board
/BIRQ: J1.a28, J2.a28, R7.1, U5.21 (~IRQ), U10.15 (I2b); also elsewhere on the board
/BLK_B: U9.13 (I1b), U11.21 (BLK_B)
/BNMI: J1.a29, J2.a29, R6.1, U10.17 (I3b); also elsewhere on the board
/BNRDS: J1.b5, J2.b5, U9.12 (O3a); also elsewhere on the board
/BNWDS: J1.b4, J2.b4, U9.14 (O2a); also elsewhere on the board
/BPH2: J1.b29, J2.b29, U5.25 (02), U9.18 (O0a); also elsewhere on the board
/BPiRX: J1.a24, J2.a24, R54.1, U10.8 (I3a); also elsewhere on the board
/BPiTX: J1.a23, J2.a23, U10.14 (O2a); also elsewhere on the board
/BRDY: J1.a25, J2.a25, R9.1, U10.11 (I0b); also elsewhere on the board
/BRW: J1.b30, J2.b30, U5.22 (R/~W), U9.16 (O1a); also elsewhere on the board
/BSO: J1.a26, J2.a26, R8.1, U10.13 (I1b); also elsewhere on the board
/BSYN: J1.a30, J2.a30, U9.9 (O0b); also elsewhere on the board
/BUF_DIR: U2.1 (A->B), U11.41 (BUF_DIR)
/CA1: J1.a22, J2.a22, U5.40 (CA1); also elsewhere on the board
/CA2: J1.a21, J2.a21, U5.39 (CA2); also elsewhere on the board
/CAS_out: U10.2 (I0a), U11.84 (CAS_out)
/CB1: J1.a12, J2.a12, U5.18 (CB1); also elsewhere on the board
/CB2: J1.a11, J2.a11, U5.19 (CB2); also elsewhere on the board
/CS_BUF: U2.19 (CE), U11.22 (CS_BUF)
/CS_RAM: U1.8 (~CE), U6.22 (~CE), U11.9 (CS_RAM)
/CS_ROM: U7.22 (CE), U11.7 (CS_ROM)
/CS_TUBE: J5.11, U11.42 (CS_TUBE); also elsewhere on the board
/CS_VIA: U5.23 (~CS2), U11.20 (CS_VIA)
/D0: J5.24, U1.9 (I/O0), U2.18 (B0), U6.13 (I/O0), U7.13 (D0), U11.38 (D0); also elsewhere on the board
/D1: J5.21, U1.10 (I/O1), U2.17 (B1), U6.14 (I/O1), U7.14 (D1), U11.39 (D1); also elsewhere on the board
/D2: J5.19, U1.13 (I/O2), U2.16 (B2), U6.15 (I/O2), U7.15 (D2), U11.40 (D2); also elsewhere on the board
/D3: J5.23, U1.14 (I/O3), U2.15 (B3), U6.17 (I/O3), U7.17 (D3), U11.1 (D3); also elsewhere on the board
/D4: J5.15, U1.31 (I/O4), U2.14 (B4), U6.18 (I/O4), U7.18 (D4), U11.2 (D4); also elsewhere on the board
/D5: J5.16, U1.32 (I/O5), U2.13 (B5), U6.19 (I/O5), U7.19 (D5), U11.3 (D5); also elsewhere on the board
/D6: J5.18, U1.35 (I/O6), U2.12 (B6), U6.20 (I/O6), U7.20 (D6), U11.4 (D6); also elsewhere on the board
/D7: J5.22, U1.36 (I/O7), U2.11 (B7), U6.21 (I/O7), U7.21 (D7), U11.5 (D7); also elsewhere on the board
/DAC_VA: J10.1, J18.2, U12.8 (VA)
/DAC_VB: J11.1, J18.9, U12.6 (VB)
/IRQ: U10.5 (O2b), U11.24 (IRQ)
/NMI: U10.3 (O3b), U11.23 (NMI)
/NRDS: U1.37 (~OE), U6.24 (~OE), U7.24 (OE), U9.8 (I3a), U11.17 (NRDS)
/NWDS: U1.15 (~WE), U6.29 (~WE), U7.31 (WE), U9.6 (I2a), U11.16 (NWDS)
/PA0: J1.a20, J2.a20, U5.2 (PA0); also elsewhere on the board
/PA1: J1.a19, J2.a19, U5.3 (PA1); also elsewhere on the board
/PA2: J1.a18, J2.a18, U5.4 (PA2); also elsewhere on the board
/PA3: J1.a17, J2.a17, U5.5 (PA3); also elsewhere on the board
/PA4: J1.a16, J2.a16, U5.6 (PA4); also elsewhere on the board
/PA5: J1.a15, J2.a15, U5.7 (PA5); also elsewhere on the board
/PA6: J1.a14, J2.a14, U5.8 (PA6); also elsewhere on the board
/PA7: J1.a13, J2.a13, U5.9 (PA7); also elsewhere on the board
/PB0: J1.a10, J2.a10, U5.10 (PB0); also elsewhere on the board
/PB1: J1.a9, J2.a9, U5.11 (PB1); also elsewhere on the board
/PB2: J1.a8, J2.a8, U5.12 (PB2); also elsewhere on the board
/PB3: J1.a7, J2.a7, U5.13 (PB3); also elsewhere on the board
/PB4: J1.a6, J2.a6, U5.14 (PB4); also elsewhere on the board
/PB5: J1.a5, J2.a5, U5.15 (PB5); also elsewhere on the board
/PB6: J1.a4, J2.a4, U5.16 (PB6); also elsewhere on the board
/PB7: J1.a3, J2.a3, U5.17 (PB7); also elsewhere on the board
/PHI2: J5.26, U9.2 (I0a), U11.18 (PHI2); also elsewhere on the board
/PiRX: J5.10, U10.12 (O3a); also elsewhere on the board
/PiTX: J5.8, U10.6 (I2a); also elsewhere on the board
/RDY: U10.9 (O0b), U11.92 (RDY)
/RST: J1.b6, J2.b6, J5.7, J14.20, R35.1, U5.34 (~RESET), U11.62 (RST_in); also elsewhere on the board
/RW: J5.12, U9.4 (I1a), U11.19 (R/W); also elsewhere on the board
/SO: U10.7 (O1b), U11.90 (SO)
/SYNC: U9.11 (I0b), U11.91 (SYNC)
GNDD: C1.2, C2.2, C3.2, C4.2, C5.2, C6.2, C7.2, C8.2, C9.2, C10.2, C11.2, C12.2, C13.2, C14.2, C15.2, C16.2, C17.2, C18.2, C19.2, C20.2, C25.2, C27.2, D1.1 (K), D2.1 (K), J1.a32, J1.b32, J2.a32, J2.b32, J4.2 (Ext), J5.6, J5.9, J5.14, J5.20, J5.25, J5.30, J5.34, J5.39, J7.2, J8.5, J8.6, J8.7, J8.8, J8.10, J9.3 (VSS), J9.6 (VSS), J14.26, J15.1, J16.3, J17.3, J18.1, J19.2, LS1.2, R1.1, R2.1, R3.1, R23.2, R48.1, R51.1, RV1.3, U1.12 (GND), U1.34 (GND), U2.10 (GND), U3.1 (OEa), U3.10 (GND), U3.19 (OEb), U4.1 (OEa), U4.10 (GND), U4.19 (OEb), U5.1 (GND), U6.16 (GND), U7.16 (GND), U8.2 (GND), U9.1 (OEa), U9.10 (GND), U9.19 (OEb), U10.1 (OEa), U10.10 (GND), U10.19 (OEb), U11.26 (GND), U11.35 (GND), U11.66 (GND), U11.75 (GND), U11.87 (GND), U12.7 (Vss), U13.4 (Gnd), U14.8 (GND), U15.1 (OEa), U15.10 (GND), U15.19 (OEb), U16.2 (-), U16.4 (GND); also elsewhere on the board
unnamed: C20.1, J12.3, R21.1, R23.1
unnamed: C21.1, R52.2
unnamed: C21.2, J10.2
unnamed: C22.1, R53.2
unnamed: C22.2, J11.2
unnamed: C23.1, RV2.3, RV3.3
unnamed: C23.2, U11.81 (Audio)
unnamed: C25.1, R46.2, U13.2 (-)
unnamed: C26.1, C28.1, U16.5
unnamed: C26.2, R48.2
unnamed: C27.1, R49.1, R50.1, R51.2
unnamed 122: C28.2, J14.21, LS1.1; also elsewhere on the board
unnamed: C29.1, J13.1, J18.8
unnamed: C29.2, R49.2, U13.5 (+)
unnamed: D1.2 (A), R10.2
unnamed: D2.2 (A), R11.2
unnamed: D3.1 (K), U11.46 (Vin)
unnamed: D4.1 (K), U11.6 (Vin)
unnamed: D5.1 (K), U15.9 (O0b)
unnamed: D5.2 (A), J14.8, R31.1, U11.56 (PB3)
unnamed: D6.1 (K), U15.5 (O2b)
unnamed: D6.2 (A), J14.4, R33.1, U11.53 (PB1)
unnamed: D7.1 (K), U15.12 (O3a)
unnamed: D7.2 (A), J14.10, R30.1, U11.57 (PB4)
unnamed: D8.1 (K), U15.7 (O1b)
unnamed: D8.2 (A), J14.6, R32.1, U11.54 (PB2)
unnamed: D9.1 (K), U15.3 (O3b)
unnamed: D9.2 (A), J14.2, R34.1, U11.52 (PB0)
unnamed: J3.2, U6.30 (A18)
unnamed: J3.3, R4.2
unnamed 141: J5.2, J5.4, J6.1; also elsewhere on the board
unnamed: J8.1, R14.2, R17.2
unnamed: J8.2, R19.2, R20.2
unnamed: J8.3, R22.2, R24.2
unnamed: J8.13, R25.2
unnamed: J8.14, R12.2
unnamed: J9.1 (CD/DAT3), R16.2, U11.47 (MMC_SS)
unnamed: J9.2 (CMD), R15.2, U11.44 (MMC_MOSI)
unnamed: J9.5 (CLK), R18.2, U11.45 (MMC_CLK)
unnamed: J9.7 (DAT0), R13.2, U11.43 (MMC_MISO)
unnamed: J12.2, J18.15
unnamed: J13.2, U15.2 (I0a)
unnamed: J13.3, R40.2, U13.1
unnamed: J14.1, U14.1 (~Q0)
unnamed: J14.3, U14.2 (~Q1)
unnamed: J14.5, U14.3 (~Q2)
unnamed: J14.7, U14.4 (~Q3)
unnamed: J14.9, U14.5 (~Q4)
unnamed: J14.11, U14.6 (~Q5)
unnamed: J14.12, R29.1, U11.58 (PB5)
unnamed: J14.13, U14.7 (~Q6)
unnamed: J14.14, Q2.3 (S), R28.1, R39.2, U11.59 (PB6)
unnamed: J14.15, U14.9 (~Q7)
unnamed: J14.16, Q4.3 (S), R27.1, R37.2, U11.60 (PB7)
unnamed: J14.17, U14.10 (~Q8)
unnamed: J7.1, J14.18, R26.1, U11.61 (PC6)
unnamed: J14.19, U14.11 (~Q9)
unnamed: J15.2, RV2.2
unnamed: J15.3, J15.5, RV1.1
unnamed: J15.4, RV3.2
unnamed: J16.1, Q3.1 (D), R41.2
unnamed: J16.5, Q1.1 (D), R43.2
unnamed: J17.1, Q4.1 (D), R42.2
unnamed: J17.5, Q2.1 (D), R44.2
unnamed: J18.3, R56.1, U15.15 (I2b)
unnamed: J18.4, R58.1, U15.11 (I0b)
unnamed: J18.5, J19.3, U15.6 (I2a)
unnamed: J18.10, R55.1, U15.17 (I3b)
unnamed: J18.11 (P111), R57.1, U15.13 (I1b)
unnamed: J18.12, R59.1, U15.8 (I3a)
unnamed: J18.13, J19.1, U15.16 (O1a)
unnamed: Q1.3 (S), R38.2, U11.72 (MOUSE_CLOCK)
unnamed: Q3.3 (S), R36.2, U11.73 (MOUSE_DATA)
unnamed: R5.1, U5.24 (CS1)
unnamed: R10.1, U11.82 (MMC_LED_RED)
unnamed: R11.1, U11.83 (MMC_LED_GREEN)
unnamed: R12.1, U11.74 (VGA_VSYNC)
unnamed: R14.1, U11.80 (VGA_RED1)
unnamed: R17.1, U11.89 (VGA_RED2)
unnamed: R19.1, U11.79 (VGA_GREEN1)
unnamed: R20.1, U11.78 (VGA_GREEN2)
unnamed: R22.1, U11.77 (VGA_BLUE1)
unnamed: R24.1, U11.88 (VGA_BLUE2)
unnamed: R25.1, U11.76 (VGA_HSYNC)
unnamed: R40.1, R45.2, U13.3 (+)
unnamed: R45.1, R47.2, U13.7
unnamed: R46.1, R47.1, U13.6 (-)
unnamed: R52.1, RV2.1
unnamed: R53.1, RV3.1
unnamed: RV1.2, U16.3 (+)
unnamed: U11.48 (PA0), U14.15 (A)
unnamed: U11.49 (PA1), U14.14 (B)
unnamed: U11.50 (PA2), U14.13 (C)
unnamed: U11.51 (PA3), U14.12 (D)
unnamed: U11.63 (DAC_SCK), U12.3 (SCK)
unnamed: U11.64 (DAC_LDAC), U12.5 (~LDAC)
unnamed: U11.65 (DAC_SDI), U12.4 (SDI)
unnamed: U11.67 (DAC_CS), U12.2 (~CS)
unnamed: U11.70 (SERIAL_RX), U15.14 (O2a)
unnamed: U11.71 (SER_TX), U15.4 (I1a)
unnamed: U11.85 (CAS_in), U15.18 (O0a)

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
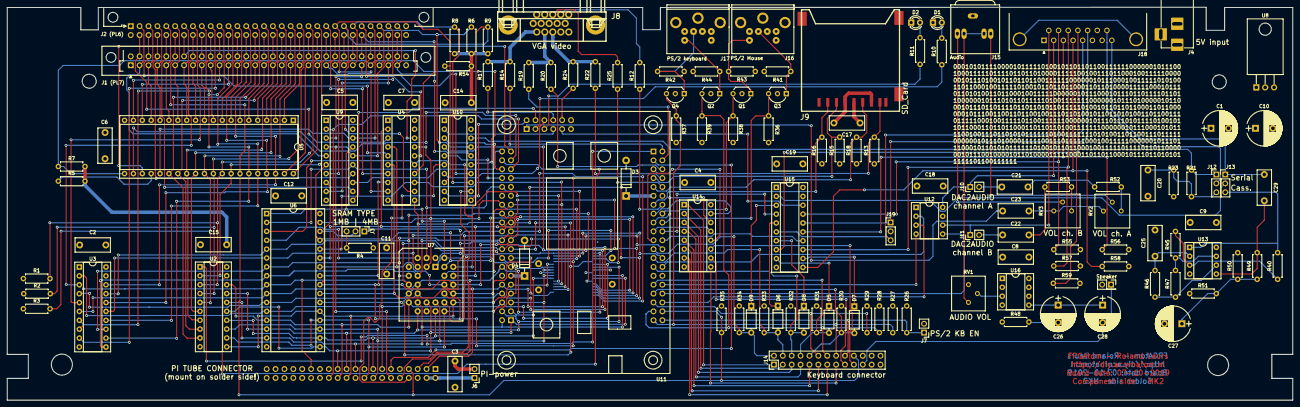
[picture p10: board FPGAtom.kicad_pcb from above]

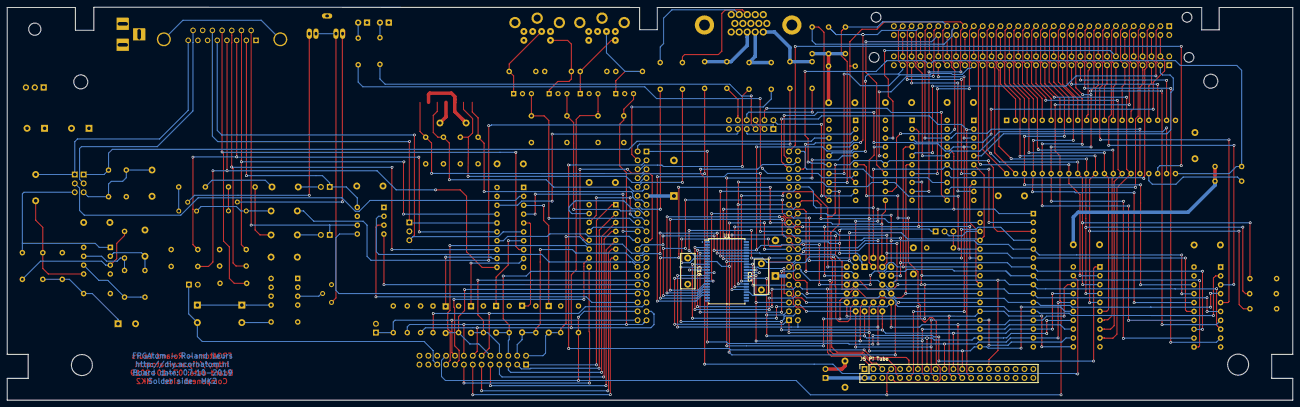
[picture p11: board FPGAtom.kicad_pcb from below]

Board: 4 copper layers, 367.5 x 112.3 mm, 143 parts (4 on the bottom side), 213 nets.

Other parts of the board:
J1 (PL7): Conn_02x32_Row_Letter_First; DIN41612_B_2x32_Vertical
J2 (PL6): Conn_02x32_Row_Letter_First; DIN41612_B_2x32_Horizontal
J5 Pi Tube: PiTube; Socket_Strip_Straight_2x20_Pitch2.54mm
Speaker: Speaker; Socket_Strip_Straight_2x01_Pitch2.54mm

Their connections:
+5V: J1 (PL7).a1, J1 (PL7).b1, J2 (PL6).a1, J2 (PL6).b1; also elsewhere on the board
/A0: J5 Pi Tube.13; also elsewhere on the board
/A1: J5 Pi Tube.3; also elsewhere on the board
/A2: J5 Pi Tube.5; also elsewhere on the board
/A3: J5 Pi Tube.29; also elsewhere on the board
/BA0: J1 (PL7).b15, J2 (PL6).b15; also elsewhere on the board
/BA1: J1 (PL7).b14, J2 (PL6).b14; also elsewhere on the board
/BA2: J1 (PL7).b13, J2 (PL6).b13; also elsewhere on the board
/BA3: J1 (PL7).b12, J2 (PL6).b12; also elsewhere on the board
/BA4: J1 (PL7).b11, J2 (PL6).b11; also elsewhere on the board
/BA5: J1 (PL7).b10, J2 (PL6).b10; also elsewhere on the board
/BA6: J1 (PL7).b9, J2 (PL6).b9; also elsewhere on the board
/BA7: J1 (PL7).b8, J2 (PL6).b8; also elsewhere on the board
/BA8: J1 (PL7).b7, J2 (PL6).b7; also elsewhere on the board
/BA9: J1 (PL7).b28, J2 (PL6).b28; also elsewhere on the board
/BA10: J1 (PL7).b27, J2 (PL6).b27; also elsewhere on the board
/BA11: J1 (PL7).b26, J2 (PL6).b26; also elsewhere on the board
/BA12: J1 (PL7).b25, J2 (PL6).b25; also elsewhere on the board
/BA13: J1 (PL7).b24, J2 (PL6).b24; also elsewhere on the board
/BA14: J1 (PL7).b3, J2 (PL6).b3; also elsewhere on the board
/BA15: J1 (PL7).b2, J2 (PL6).b2; also elsewhere on the board
/BA16: J1 (PL7).a2, J2 (PL6).a2; also elsewhere on the board
/BA17: J1 (PL7).a27, J2 (PL6).a27; also elsewhere on the board
/BA18: J1 (PL7).a31, J2 (PL6).a31; also elsewhere on the board
/BBLK_B: J1 (PL7).b31, J2 (PL6).b31; also elsewhere on the board
/BD0: J1 (PL7).b23, J2 (PL6).b23; also elsewhere on the board
/BD1: J1 (PL7).b22, J2 (PL6).b22; also elsewhere on the board
/BD2: J1 (PL7).b21, J2 (PL6).b21; also elsewhere on the board
/BD3: J1 (PL7).b20, J2 (PL6).b20; also elsewhere on the board
/BD4: J1 (PL7).b19, J2 (PL6).b19; also elsewhere on the board
/BD5: J1 (PL7).b18, J2 (PL6).b18; also elsewhere on the board
/BD6: J1 (PL7).b17, J2 (PL6).b17; also elsewhere on the board
/BD7: J1 (PL7).b16, J2 (PL6).b16; also elsewhere on the board
/BIRQ: J1 (PL7).a28, J2 (PL6).a28; also elsewhere on the board
/BNMI: J1 (PL7).a29, J2 (PL6).a29; also elsewhere on the board
/BNRDS: J1 (PL7).b5, J2 (PL6).b5; also elsewhere on the board
/BNWDS: J1 (PL7).b4, J2 (PL6).b4; also elsewhere on the board
/BPH2: J1 (PL7).b29, J2 (PL6).b29; also elsewhere on the board
/BPiRX: J1 (PL7).a24, J2 (PL6).a24; also elsewhere on the board
/BPiTX: J1 (PL7).a23, J2 (PL6).a23; also elsewhere on the board
/BRDY: J1 (PL7).a25, J2 (PL6).a25; also elsewhere on the board
/BRW: J1 (PL7).b30, J2 (PL6).b30; also elsewhere on the board
/BSO: J1 (PL7).a26, J2 (PL6).a26; also elsewhere on the board
/BSYN: J1 (PL7).a30, J2 (PL6).a30; also elsewhere on the board
/CA1: J1 (PL7).a22, J2 (PL6).a22; also elsewhere on the board
/CA2: J1 (PL7).a21, J2 (PL6).a21; also elsewhere on the board
/CB1: J1 (PL7).a12, J2 (PL6).a12; also elsewhere on the board
/CB2: J1 (PL7).a11, J2 (PL6).a11; also elsewhere on the board
/CS_TUBE: J5 Pi Tube.11; also elsewhere on the board
/D0: J5 Pi Tube.24; also elsewhere on the board
/D1: J5 Pi Tube.21; also elsewhere on the board
/D2: J5 Pi Tube.19; also elsewhere on the board
/D3: J5 Pi Tube.23; also elsewhere on the board
/D4: J5 Pi Tube.15; also elsewhere on the board
/D5: J5 Pi Tube.16; also elsewhere on the board
/D6: J5 Pi Tube.18; also elsewhere on the board
/D7: J5 Pi Tube.22; also elsewhere on the board
/PA0: J1 (PL7).a20, J2 (PL6).a20; also elsewhere on the board
/PA1: J1 (PL7).a19, J2 (PL6).a19; also elsewhere on the board
/PA2: J1 (PL7).a18, J2 (PL6).a18; also elsewhere on the board
/PA3: J1 (PL7).a17, J2 (PL6).a17; also elsewhere on the board
/PA4: J1 (PL7).a16, J2 (PL6).a16; also elsewhere on the board
/PA5: J1 (PL7).a15, J2 (PL6).a15; also elsewhere on the board
/PA6: J1 (PL7).a14, J2 (PL6).a14; also elsewhere on the board
/PA7: J1 (PL7).a13, J2 (PL6).a13; also elsewhere on the board
/PB0: J1 (PL7).a10, J2 (PL6).a10; also elsewhere on the board
/PB1: J1 (PL7).a9, J2 (PL6).a9; also elsewhere on the board
/PB2: J1 (PL7).a8, J2 (PL6).a8; also elsewhere on the board
/PB3: J1 (PL7).a7, J2 (PL6).a7; also elsewhere on the board
/PB4: J1 (PL7).a6, J2 (PL6).a6; also elsewhere on the board
/PB5: J1 (PL7).a5, J2 (PL6).a5; also elsewhere on the board
/PB6: J1 (PL7).a4, J2 (PL6).a4; also elsewhere on the board
/PB7: J1 (PL7).a3, J2 (PL6).a3; also elsewhere on the board
/PHI2: J5 Pi Tube.26; also elsewhere on the board
/PiRX: J5 Pi Tube.10; also elsewhere on the board
/PiTX: J5 Pi Tube.8; also elsewhere on the board
/RST: J1 (PL7).b6, J2 (PL6).b6, J5 Pi Tube.7; also elsewhere on the board
/RW: J5 Pi Tube.12; also elsewhere on the board
GNDD: J1 (PL7).a32, J1 (PL7).b32, J2 (PL6).a32, J2 (PL6).b32, J5 Pi Tube.6, J5 Pi Tube.9, J5 Pi Tube.14, J5 Pi Tube.20, J5 Pi Tube.25, J5 Pi Tube.30, J5 Pi Tube.34, Speaker.2; also elsewhere on the board
unnamed 122: Speaker.1; also elsewhere on the board
unnamed 141: J5 Pi Tube.2, J5 Pi Tube.4; also elsewhere on the board
